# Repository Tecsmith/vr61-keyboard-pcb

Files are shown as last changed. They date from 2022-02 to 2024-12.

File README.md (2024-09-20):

# VR61 - MicroMod 60% Custom Keyboard PCB

***Featuring SparkFun's MicroMod Processor Boards***

---

> Very happy to announce that [PCBWay](https://pcbway.com) has gratefully sponsored the production of the first 5 RevA PCBs, and a partial assembly service *(all but the USB-C, Hot-Swap Sockets, JST-ph4 & SK6812's)*, for this project.
>
> Official Sponsor - PCBWay (https://pcbway.com/)
>
> Thank you [PCBWay](https://pcbway.com/)!

Please follow the updates to this production process on the [changelog](CHANGELOG.md) page.

---

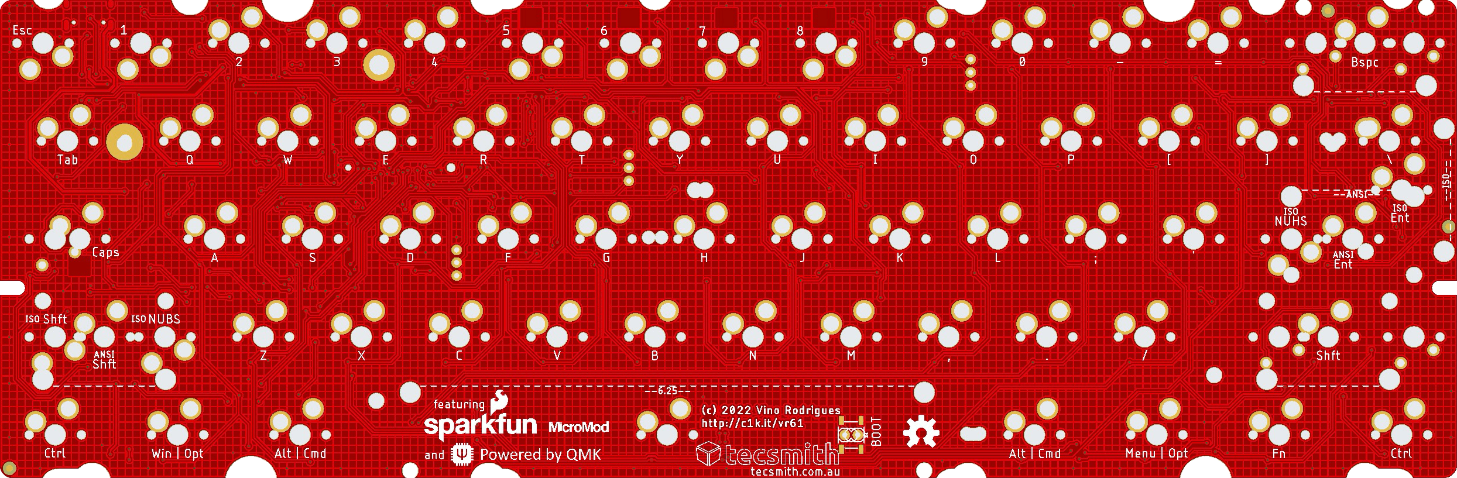
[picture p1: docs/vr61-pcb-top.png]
PCB Top View


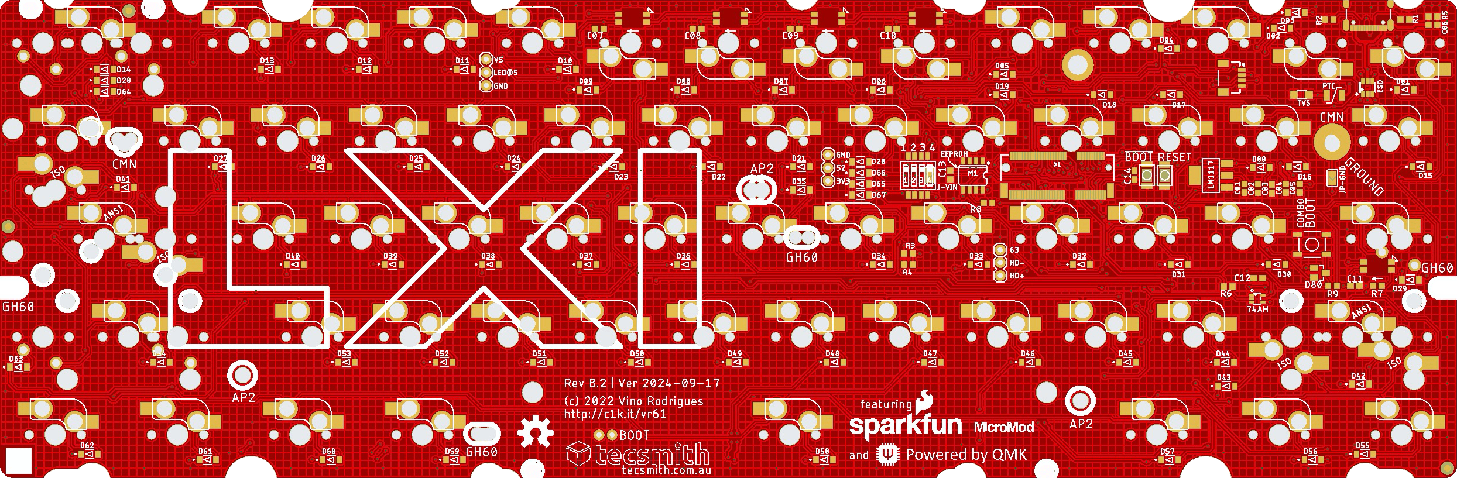
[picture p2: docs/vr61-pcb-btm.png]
PCB Bottom View


Published as Open Source, under a [ Creative Commons Share-alike 4.0 International](LICENSE.md).  

### **Rev B** &nbsp; 

> &#128077; **WORKING, OK TO BUILD**

* [PDF Schematic](docs/vr61-revB.2.pdf) <sup>1</sup>
* [EAGLE PCB](EAGLE/vr61/vr61-revB.brd)
* [EAGLE Schematic](EAGLE/vr61/vr61-revB.sch)

* Notes:
    - Keymap Working on both STM32 and PR2040
    - *(Optional EEPROM not tested yet)*

> <sup>1</sup> = *RevB.1 schematic is [here](docs/vr61-revB.pdf)*

### **Rev A** &nbsp; 

> &#9888; Do not use this revision, it has terminal flaws.

* ~~[PDF Schematic](docs/vr61-revA.pdf)~~
* ~~EAGLE PCB~~ <sup>2</sup>
* ~~EAGLE Schematic~~ <sup>2</sup>

> <sup>2</sup> = *to access these files please use the Github history*

### QMK code:

* https://github.com/Tecsmith/vr61-keyboard-qmk
* USB Identifier registered with [pid.codes](https://pid.codes/) = [`1209`/`7672`](https://pid.codes/1209/7672/)

### Layout

* [KLE link](http://www.keyboard-layout-editor.com/#/gists/c812c931186e45a5acbc3e217ef4f161)

*****

## Features

**VR61-MicroMod** - using SparkFun MicroMod STM32 or RP2040 M.2 module

### Core Design Elements

- 60% form factor
    - Design to be compatible with GH60/HK60 cases
    - Also compatible with Anne Pro 2 cases *(~~drop in~~ QMK replacement for existing AP2's or AP2 cases)* *[Removal of battery and minor case cut in the battery compartment required.]*
    - MicroMod positioned in case *"battery compartment"* space.

- QMK + VIA default f/w
    - Wired only *(no wireless)*
    - Default key-maps for Mac users

- User choice of microcontroller
    
    - [STM32 Processor](https://www.sparkfun.com/products/17713) 
        - ARM Cortex-M4, 168MHz, 1MB Flash, 192kB SRAM
        - https://github.com/Tecsmith/vr61-keyboard-qmk

    - [RP2040 Processor](https://www.sparkfun.com/products/17720) 
        - ARM Cortex-M0+, 133MHz, 128Mb Flash (16MB external), 264kB SRAM in six banks
        
- USB-C *(left side)*

    ... but also optional JST connector for [ai03 Unified C3 Daughterboard](https://github.com/ai03-2725/Unified-Daughterboard)

- ESD, Over Voltage and Over Current protection

    ... and cable shield noise filter

- Hot-swap, 5 pin switch slots

- PCB mounted stabs compatibility

- Dual ANSI / ISO layout support

- 61-Key (ANSI) / 62-Key (ISO) Layout [1.25, 1.25, 1.25, **6.25**, 1.25, 1.25, 1.25, 1.25] bottom row *(a.k.a. "Poker" / "POK3R" Layout)*

- Limited RGB LEDs *(SK6812 mini-E)*

    - RGB Caps Lock Indicator

    - North facing RGB's under the `5`, `6`, `7` & `8` keys for layer indicator

    - WS2812/SK6812 breakout for optional external LEDs

- Spare GPIO pins (`52` & `63`) breakout for expansion

   ... e.g., ~~add speaker~~

- Both `[Reset]` and `[Boot]` buttons *(as per MicroMod ref. design)*

    ... plus under space-bar Boot pins for bootload without disassembly *(press while inserting cable for bootloader function)*

---
Made with &#9829; by Vino Rodrigues

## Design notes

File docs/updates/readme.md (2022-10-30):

# Updates
All notable updates to this project will be documented in this file.

*(The format is based on [Keep a Changelog](https://keepachangelog.com/en/1.0.0/).)*

> [PCBWay](https://pcbway.com) graciously offered to sponsor the prototype build of this keyboard

<p align="center">

</p>

---

# Rev B - History

## 2022-08-30

- Placed order with PCBWay ... added Micromod and USB connector to this assembly set

## 2022-09-1

- PCBWay confirmed sourcing of all parts
- Order paid and go-ahead given

## 2022-10-17

- PCBWay order of 5 prototype bards arrived.  Some issues were encountered with the `74AHCT1G125GW` module footprint.

## 2022-10-23

- First prototype fully built
- Code implemented, but no success of getting the LED's to work

## 2022-10-27

- Finally got the LED's to work
- Issue was with the code and the PWM settings of the STM32 processor
- Cannot get the PR2040 code to work -- parking the RP2040 LED implementation, the keymap works however

## 2022-10-30

- Final code on the keymaps completed
- Minor edits to the PCB

## Pending

- PR2040 LED not working yet
- SPI EEPROM not tested *(not even attempted, yet)*

---

# Rev A - History

## 2022-06-17

- Order placed with PCBWay and confirmation received.

## 2022-06-28

### Finished goods photos sent

- Got an email will the finished build - shipping to me next.
  
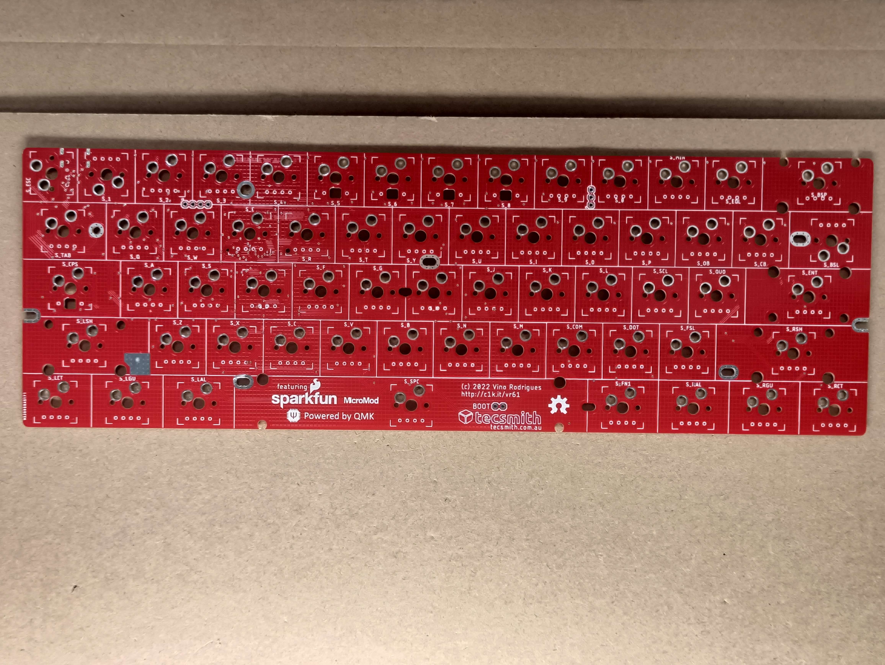
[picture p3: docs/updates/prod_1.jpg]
  
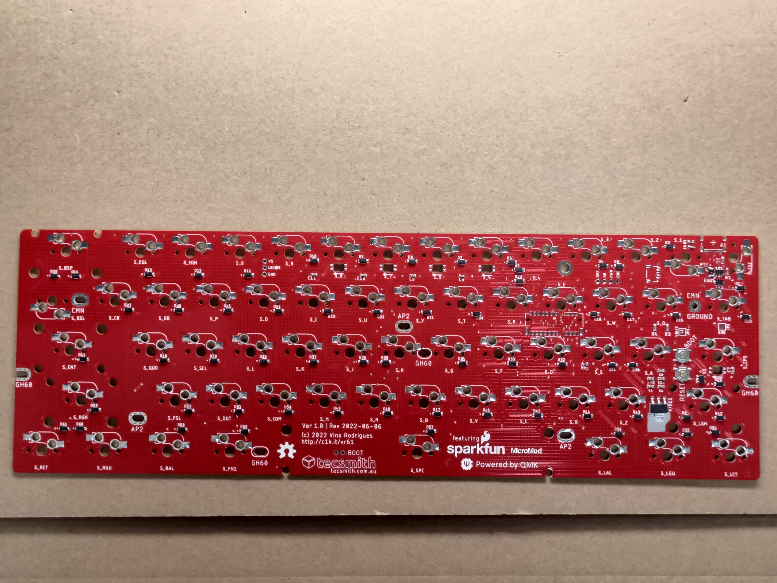
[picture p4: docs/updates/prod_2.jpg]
  
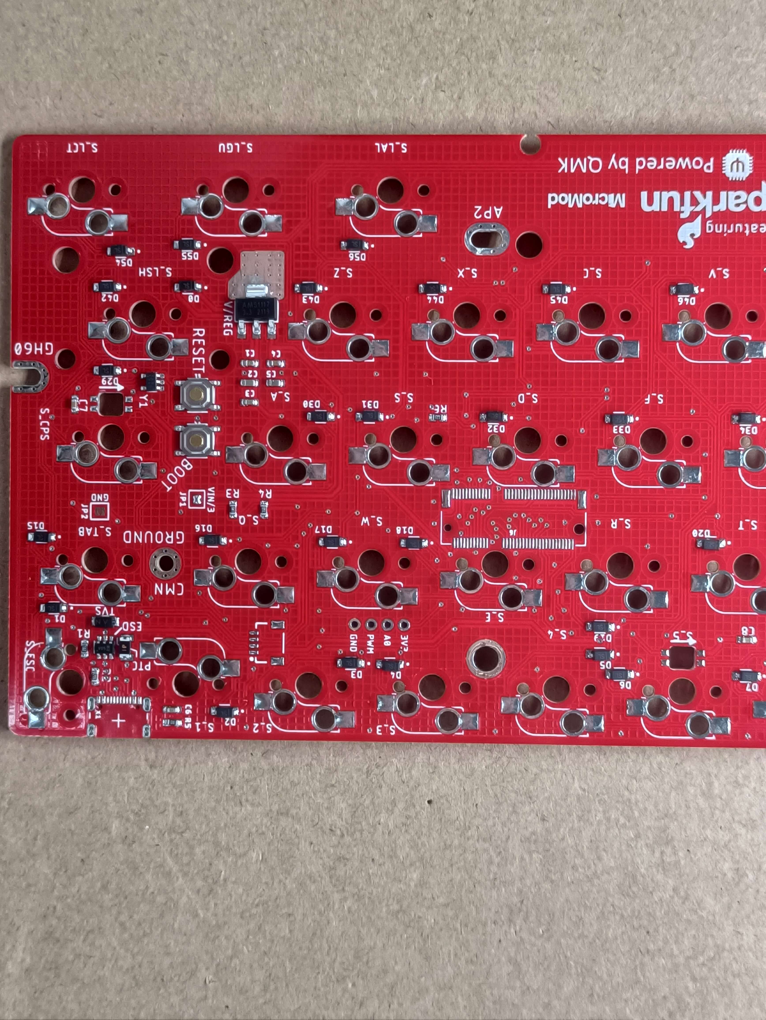
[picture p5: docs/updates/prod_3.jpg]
  
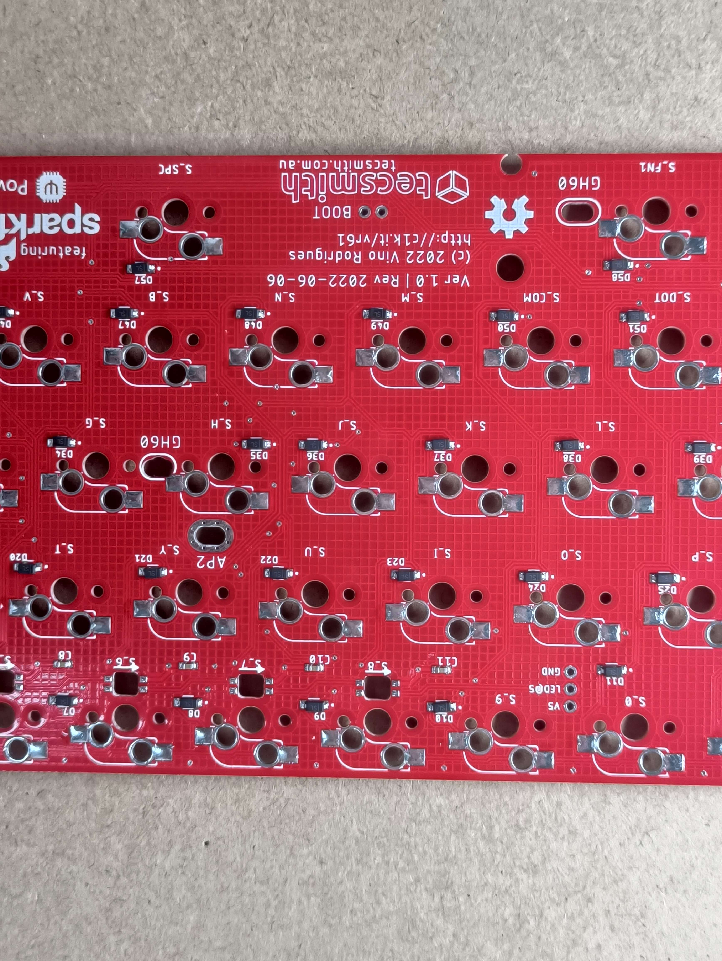
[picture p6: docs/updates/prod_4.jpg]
  
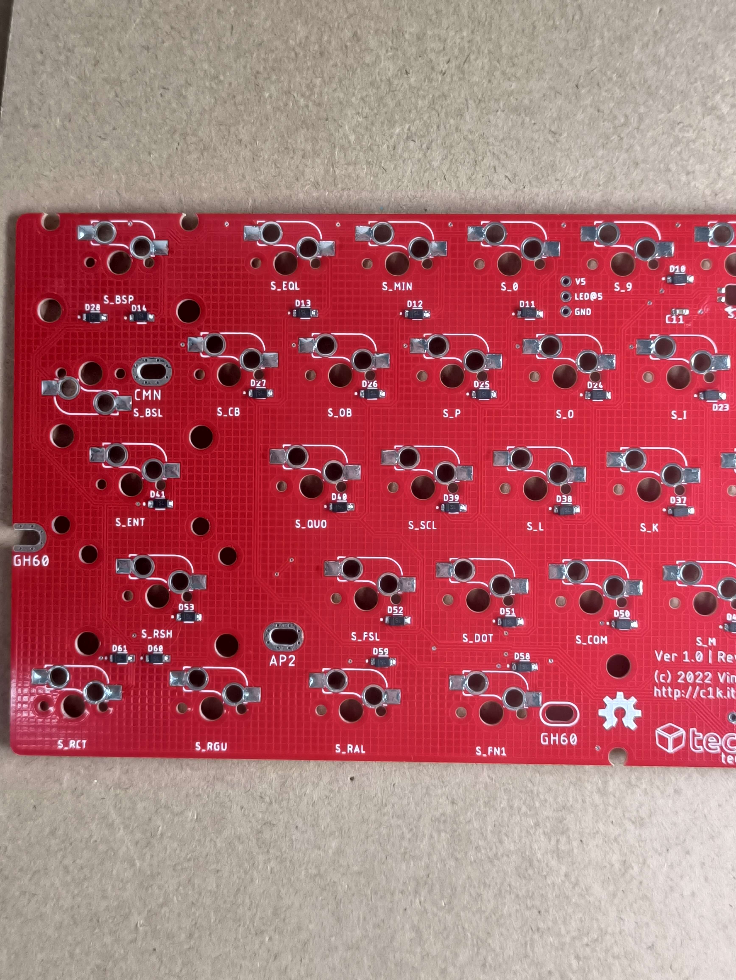
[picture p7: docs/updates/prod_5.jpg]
  

## 2022-07-15

### PCB delivered

- Arrived in Sydney via DHL.  No issues.

## 2022-07-18

### Initial testing

- Soldered on UBS connector
- Soldered on MicroMod connector
- Installed SMT32 module and Tested key matrix - ***IT WORKS!***
  - Must say I build 2 boards and both didn't work at first - fault finding lead to discovery that one of the USB data lines was grounded.  On one board I stripped out the ESD thinking that was up-side-down... it wasn't.  And then I found it.  A solder short on the MicroMod connector between pin 5 and 7... on BOTH!
  - Must also say the soldering that Micromod connector was super difficult!
  - Next time I will have all the components installed by the supplier!
- PCBWay did an amazing job on the PCB!

## 2022-07-20

### Declaring Rev A as FAILED :(

Came across some terminal issues when compiling the code and attempting to retro-fit the PCB into a AnnePro2 case.

- The `ESC` key is off to right by 1mm.  Checked the CAD `.sch` and say that somehow I'd moved it and missed that it was off by 1mm.  Must have been on the rotation and I didn't double check.
- The LED implementation does not work electronically.  Somewhere between the MCU the Level Shifter and the first LED something happens and I blow the 1st LED.  Soldered on 3 replacements, all blown. Bypass the `Caps-Lock` position and made `5` key 1st - that blew to.  Need to relook at more ref. designs for this.

#### Next

- Everything else seems to work.  Code also works...
- ... but I'd assumed the memory IC on the MicroMod was an EEPROM. **It's not** .. it's Flash! *(Rookie assumption!)*  Will implement an I²C EEPROM as the 100,000 write cycles of the W25Q32FV Flash is far, far less than the 4,000,000 of an external EEPROM like the ST M24Cx IC's.
> Wondering what I can do with the Flash tho ... seems a waste.

---

# Rev A - Issues
> as discovered ... to implement in rev. B

- [ ] ~~Position of MicroMod connector is too low, does not fit in AP2 case without minor cutting - possibly move this up as far as it can go.~~ *[Cannot move as it will interfere with key]*
- [x] Position of the BOOT pads in the space bar area should align to the AP2 slot
- [x]  Spacing of key was generated by [Kalerator](https://kalerator.clueboard.co/) ... but this generator spaces the keys at 19mm.  **However***... spacing for keyboards is **19.05mm**!

#### Post FAIL / Rev B WIP

- [x] Correct `ESC` key position
- [x] New LED / Level Shift design
- [ ] ~~Bring out I²C from Micromod~~ *[I²C not usable as pins are shared with matrix pins for PR2040 module]*
- [x] ~~Add I²C EEPROM module~~ *[Changed this to SPI]*
- [x] Move USB 0.5mm right to align to AP2 case slot. *(Uncertain this will jeopardise the GH60 cases.)*

## Maybe

- [x] Move 5678 LED's to north-facing.
- [x] Possibly incorporate a ISO layout?
- [ ] ~~Possibly incorporate a 64-key layout?~~ *[Does not fit]*

> Rev B is ready *[26 Aug 2022]*

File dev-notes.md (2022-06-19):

# Random Notes

***(Not part of the project)***

## MicroMod reference boards

- SparkFun MicroMod ATP Carrier Board - https://github.com/sparkfun/MicroMod_ATP_Carrier_Board
- SparkFun STM32 MicroMod Processor - https://github.com/sparkfun/MicroMod_STM32_Processor
- SparkFun MicroMod Processor RP2040 - https://github.com/sparkfun/MicroMod_Processor-RP2040

## Tools Used

- Layout
    - [Keyboard Layout Editor](http://www.keyboard-layout-editor.com/)
- EAGLE key position generator
    - [Kalerator](https://kalerator.clueboard.co/)
- KiCad
    - [@ai03 's PCB Designer Guide](https://wiki.ai03.com/books/pcb-design/chapter/pcb-designer-guide)
    - [@ruiqimao 's Keyboard PCB Guide](https://github.com/ruiqimao/keyboard-pcb-guide)
- Plate
    - [Swill's Plate & Case Builder](http://builder.swillkb.com/)
    - [Keyboard CAD Assistant](http://www.keyboardcad.com/)

## Possible design aids

- Closest is the BM60 Poker - but that's not open source.
- [**Acheron Project**](https://github.com/orgs/AcheronProject) - [acheronproject.com](https://acheronproject.com/)
    - [KeebsPCB](https://github.com/AcheronProject/KeebsPCB) &#x26A0;
    - [ArcticPCB](https://github.com/AcheronProject/ArcticPCB)
    - [Tsuki](https://github.com/AcheronProject/Tsuki)
    - [Doddle60](https://github.com/AcheronProject/Doddle60)
- [GH60](https://github.com/komar007/gh60), also [read this](http://blog.komar.be/gh60-evolution/)
- [Bakeneko 60](https://github.com/kkatano/bakeneko-60)
- [Voyager 60](https://github.com/ai03-2725/Voyager60)
- [Plain6-C](https://github.com/evyd13/plain60-c)
- *(a bit off the design footprint)* [Grabert KB](https://github.com/KoBussLLC/grabert-hardware)
- for M.2 example see [github.com/makerdiary/python-keyboard](https://github.com/makerdiary/python-keyboard) & [makerdiary.com/m60](https://makerdiary.com/pages/m60-mechanical-keyboard)

## @tzarc Notes

Explicitly listed below, pins are available on all of:
> STM32, SAMD51, Teensy, RP2040, nRF52

- A0/A1 available
- PWM0/PWM1 available
- D0/D1 available
- G0-G3 available
- AUD LRCLK/BCLK available
- I2C SCL/SDA/INT available
- SPI SCK/SDO/SDI/CS available

further:

- G4-G7 are unusable on RP2040 (collides with SPI)
- CAN only available on STM32, SAMD51, Teensy
- G11/SWO only available on STM32, SAMD51, Teensy

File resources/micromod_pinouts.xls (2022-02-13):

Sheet: Sheet1
 | STM32 PROCESSOR PINOUT |  |  |  |  |  |  |  | MICROMOD GENERAL PINOUT TABLE
 | STM32 Pin | Primary Function | Bottom | Top | Primary Function | STM32 Pin |  |  | Function |  |  |  | Bottom | Top | Function
 |  |  | Pin | Pin |  |  |  |  |  |  |  |  | Pin | Pin
 | - | (Not Connected) |  | 75 | GND | - |  |  |  |  |  | (Not Connected) |  | 75 | GND
 | - | 3.3V | 74 | 73 | G5 / BUS5 | PC13 | C13 |  |  |  |  | 3.3V | 74 | 73 | G5 / BUS5 |  |  | ?
 | - | - | 72 | 71 | G6 / BUS6 | PC2 | C2 |  |  |  |  | RTC_3V_BATT | 72 | 71 | G6 / BUS6 |  |  | ?
 | - | - | 70 | 69 | - | - |  |  |  |  | SPI_CS1# | SDIO_DATA3 (I/O) | 70 | 69 | G7 / BUS7
 | - | - | 68 | 67 | - | - |  |  |  |  |  | SDIO_DATA2 (I/O) | 68 | 67 | G8
 | - | - | 66 | 65 | - | - |  |  |  |  |  | SDIO_DATA1 (I/O) | 66 | 65 | G9 | ADC_D- | CAM_HSYNC
 | - | - | 64 | 63 | G10/HOST_VBUS | PB13 | ⚠ |  |  |  | SPI_CIPO1 | SDIO_DATA0 (I/O) | 64 | 63 | G10 | ADC_D+ | CAM_VSYNC
 | - | - | 62 | 61 | SPI_CIPO (I) | PA6 | A6 |  |  |  | SPI COPI1 | SDIO_CMD (I/O) | 62 | 61 | SPI_CIPO (I) |  |  | ROW0
 | - | - | 60 | 59 | SPI_COPI (O) | PA7 | A7 |  |  |  | SPI SCK1 | SDIO_SCK (O) | 60 | 59 | SPI_COPI (O) | LED_DAT
 | - | - | 58 | 57 | SPI_SCK (O) | PA5 | A5 |  |  |  |  | AUD_MCLK (O) | 58 | 57 | SPI_SCK (O) | LED_CLK
B4 | PB4 | AUD_OUT | 56 | 55 | SPI_CS# | PC4 | C4 | COL0 | CAM_MCLK | PCM_OUT | I2S_OUT | AUD_OUT | 56 | 55 | SPI_CS# |  |  | ROW1
B5 | PB5 | AUD_IN | 54 | 53 | I2C_SCL1 (I/O) | PB6 | B6 | COL1 | CAM_PCLK | PCM_IN | I2S_IN | AUD_IN | 54 | 53 | I2C_SCL1 (I/O) |  |  | ROW2
A4 | PA4 | AUD_LRCLK | 52 | 51 | I2C_SDA1 (I/O) | PB7 | B7 | COL2 | PDM_DATA | PCM_SYNC | I2S_WS | AUD_LRCLK | 52 | 51 | I2C_SDA1 (I/O) |  |  | ROW3
B3 | PB3 | AUD_BCLK | 50 | 49 | BATT_VIN / 3 (I - ADC) (0 to 3.3V) | - |  | COL3 | PDM_CLK | PCM_CLK | I2S_SCK | AUD_BCLK | 50 | 49 | BATT_VIN / 3 (I - ADC) (0 to 3.3V)
C9 | PC9 | G4 / BUS4 | 48 | 47 | PWM1 | PC7 | C7 | COL4 |  |  |  | G4 / BUS4 | 48 | 47 | PWM1 |  |  | ROW4
C8 | PC8 | G3 / BUS3 | 46 | 45 | GND | - |  | COL5 |  |  |  | G3 / BUS3 | 46 | 45 | GND
A0 | PA0 | G2 / BUS2 | 44 | 43 | CAN_TX | PB9 | B9 | COL6 |  |  |  | G2 / BUS2 | 44 | 43 | CAN_TX |  |  | ?
A8 | PA8 | G1 / BUS1 | 42 | 41 | CAN_RX | PB8 | B8 | COL7 |  |  |  | G1 / BUS1 | 42 | 41 | CAN_RX |  |  | ?
D2 | PD2 | G0 / BUS0 | 40 | 39 | GND | - |  | COL8 |  |  |  | G0 / BUS0 | 40 | 39 | GND
B0 | PB0 | A1 | 38 | 37 | USBHOST_D- | PB14 | B14 | COL9 |  |  |  | A1 | 38 | 37 | USBHOST_D-
 | - | GND | 36 | 35 | USBHOST_D+ | PB15 | B15 | COL10 |  |  |  | GND | 36 | 35 | USBHOST_D+
C5 | PC5 | A0 | 34 | 33 | GND | - |  |  |  |  |  | A0 | 34 | 33 | GND
C6 | PC6 | PWM0 | 32 | 31 | Module Key | - |  | CAPS-LED |  |  |  | PWM0 | 32 | 31 | Module Key
 | - | Module Key | 30 | 29 | Module Key | - |  |  |  |  |  | Module Key | 30 | 29 | Module Key
 | - | Module Key | 28 | 27 | Module Key | - |  |  |  |  |  | Module Key | 28 | 27 | Module Key
 | - | Module Key | 26 | 25 | Module Key | - |  |  |  |  |  | Module Key | 26 | 25 | Module Key
 | - | Module Key | 24 | 23 | SWDIO | PA13 | A14 |  |  |  |  | Module Key | 24 | 23 | SWDIO |  |  | ?
 | - | - | 22 | 21 | SWCLK | PA14 | A13 |  |  |  |  | UART_TX2 (O) | 22 | 21 | SWDCK |  |  | ?
 | - | - | 20 | 19 | UART_RX1 (I) | PA3 | A3 |  |  |  |  | UART_RX2 (I) | 20 | 19 | UART_RX1 (I) |  |  | ?
C1 | PC1 | D1 | 18 | 17 | UART_TX1 (0) | PA2 | A2 | COL11 |  |  | CAM_TRIG | D1 | 18 | 17 | UART_TX1 (0) |  |  | ?
B1 | PB1 | I2C_INT# | 16 | 15 | - | - |  |  |  |  |  | I2C_INT# | 16 | 15 | UART_CTS1 (I)
B10 | PB10 | I2C_SCL (I/0) | 14 | 13 | - | - |  |  |  |  |  | I2C_SCL (I/0) | 14 | 13 | UART_RTS1 (O)
B11 | PB11 | I2C_SDA (I/0) | 12 | 11 | BOOT# (I - Open Drain) | BOOT0 | BOOT ⚠ |  |  |  |  | I2C_SDA (I/0) | 12 | 11 | BOOT (I - Open Drain) |  |  | BOOT ⚠
C0 | PC0 | D0 | 10 | 9 | - | - |  | COL12 |  |  |  | D0 | 10 | 9 | USB_VIN
B12 | PB12 | G11/HOST_ID | 8 | 7 | GND | - |  | COL13 |  |  | SWO | G11 | 8 | 7 | GND
⚠ RESET | - | RESET# (I - Open Drain) | 6 | 5 | USB_D- | PA11 | ⚠ | ⚠ RESET |  |  |  | RESET# (I - Open Drain) | 6 | 5 | USB_D- |  |  | USB D-
 | - | - | 4 | 3 | USB_D+ | PA12 | ⚠ |  |  |  |  | 3.3V_EN | 4 | 3 | USB_D+ |  |  | USB D+
 | - | 3.3V | 2 | 1 | GND | - |  |  |  |  |  | 3.3V | 2 | 1 | GND
 | AUDIO
 | UART
 | GPIO/BUS
 | I2C
 | SDIO
 | SPI
 | Dedicated

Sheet: Sheet2
MICROMOD GENERAL PIN DESCRIPTIONS
Signal Group | Signal | I/O | Description | Voltage
Power | 3.3V | I | 3.3V Source | 3.3V
 | GND |  | Return current path | 0V
 | USB_VIN | I | USB VIN compliant to USB 2.0 specification. Connect to pins on processor board that require 5V for USB functionality | 4.8-5.2V
 | RTC_3V_BATT | I | 3V provided by external coin cell or mini battery. Max draw=100μA. Connect to pins maintaining an RTC during power loss. Can be left NC. | 3V
 | 3.3V_EN | O | Controls the carrier board's main voltage regulator. Voltage above 1V will enable 3.3V power path. | 3.3V
 | BATT_VIN/3 | I | Carrier board raw voltage over 3. 1/3 resistor divider is implemented on carrier board. Amplify the analog signal as needed for full 0-3.3V range | 3.3V
Reset | Reset | I | Input to processor. Open drain with pullup on processor board. Pulling low resets processor. | 3.3V
 | Boot | I | Input to processor. Open drain with pullup on processor board. Pulling low puts processor into special boot mode. Can be left NC. | 3.3V
USB | USB_D± | I/O | USB Data ±. Differential serial data interface compliant to USB 2.0 specification. If UART is required for programming, USB± must be routed to a USB-to-serial conversion IC on the processor board.
USB Host | USBHOST_D± | I/O | For processors that support USB Host Mode. USB Data±. Differential serial data interface compliant to USB 2.0 specification. Can be left NC.
CAN | CAN_RX | I | CAN Bus receive data. | 3.3V
 | CAN_TX | O | CAN Bus transmit data. | 3.3V
UART | UART_RX1 | I | UART receive data. | 3.3V
 | UART_TX1 | O | UART transmit data. | 3.3V
 | UART_RTS1 | O | UART ready to send. | 3.3V
 | UART_CTS1 | I | UART clear to send. | 3.3V
 | UART_RX2 | I | 2nd UART receive data. | 3.3V
 | UART_TX2 | O | 2nd UART transmit data. | 3.3V
I2C | I2C_SCL | I/O | I2C clock. Open drain with pullup on carrier board. | 3.3V
 | I2C_SDA | I/O | I2C data. Open drain with pullup on carrier board | 3.3V
 | I2C_INT# | I | Interrupt notification from carrier board to processor. Open drain with pullup on carrier board. Active LOW | 3.3V
 | I2C_SCL1 | I/O | 2nd I2C clock. Open drain with pullup on carrier board. | 3.3V
 | I2C_SDA1 | I/O | 2nd I2C data. Open drain with pullup on carrier board. | 3.3V
SPI | SPI_COPI | O | SPI Controller Output/Peripheral Input. | 3.3V
 | SPI_CIPO | I | SPI Controller Input/Peripheral Output. | 3.3V
 | SPI_SCK | O | SPI Clock. | 3.3V
 | SPI_CS# | O | SPI Chip Select. Active LOW. Can be routed to GPIO if hardware CS is unused. | 3.3V
SPI/SDIO | SPI_SCK1/SDIO_CLK | O | 2nd SPI Clock. Secondary use is SDIO Clock. | 3.3V
 | SPI_COPI1/SDIO_CMD | I/O | 2nd SPI Controller Output/Peripheral Input. Secondary use is SDIO command interface. | 3.3V
 | SPI_CIPO1/SDIO_DATA0 | I/O | 2nd SPI Peripheral Input/Controller Output. Secondary use is SDIO data exchange bit 0. | 3.3V
 | SDIO_DATA1 | I/O | SDIO data exchange bit 1. | 3.3V
 | SDIO_DATA2 | I/O | SDIO data exchange bit 2. | 3.3V
 | SPI_CS1/SDIO_DATA3 | I/O | 2nd SPI Chip Select. Secondary use is SDIO data exchange bit 3. | 3.3V
Audio | AUD_MCLK | O | Audio master clock. | 3.3V
 | AUD_OUT/PCM_OUT/I2S_OUT/CAM_MCLK | O | Audio data output. PCM synchronous data output. I2S serial data out. Camera master clock. | 3.3V
 | AUD_IN/PCM_IN/I2S_IN/CAM_PCLK | I | Audio data input. PCM syncrhonous data input. I2S serial data in. Camera periphperal clock. | 3.3V
 | AUD_LRCLK/PCM_SYNC/I2S_WS/PDM_DATA | I/O | Audio left/right clock. PCM syncrhonous data SYNC. I2S word select. PDM data. | 3.3V
 | AUD_BCLK/PCM_CLK/I2S_CLK/PDM_CLK | O | Audio bit clock. PCM clock. I2S continuous serial clock. PDM clock. | 3.3V
SWD | SWDIO | I/O | Serial Wire Debug I/O. Connect if processor board supports SWD. Can be left NC. | 3.3V
 | SWDCK | I | Serial Wire Debug clock. Connect if processor board supports SWD. Can be left NC. | 3.3V
ADC | A0 | I | Analog to digital converter 0. Amplify the analog signal as needed to enable full 0-3.3V range. | 3.3V
 | A1 | I | Analog to digital converter 1. Amplify the analog signal as needed to enable full 0-3.3V range. | 3.3V
PWM | PWM0 | O | Pulse width modulated output 0. | 3.3V
 | PWM1 | O | Pulse width modulated output 1. | 3.3V
Digital | D0 | I/O | General digital input/output pin. | 3.3V
 | D1/CAM_TRIG | I/O | General digital input/output pin. Camera trigger. | 3.3V
General/Bus | G0/BUS0 | I/O | General purpose pins. Any unused processor pins should be assigned to Gx with ADC + PWM capable pins given priority (0, 1, 2, etc.) positions. The intent is to guarantee PWM, ADC and Digital Pin functionality on respective ADC/PWM/Digital pins. Gx pins do not guarantee ADC/PWM function. Alternative use is pins can support a fast read/write 8-bit or 4-bit wide bus. | 3.3V
 | G1/BUS1 | I/O |  | 3.3V
 | G2/BUS2 | I/O |  | 3.3V
 | G3/BUS3 | I/O |  | 3.3V
 | G4/BUS4 | I/O |  | 3.3V
 | G5/BUS5 | I/O |  | 3.3V
 | G6/BUS6 | I/O |  | 3.3V
 | G7/BUS7 | I/O |  | 3.3V
 | G8 | I/O | General purpose pin | 3.3V
 | G9/ADC_D-/CAM_HSYNC | I/O | Differential ADC input if available. Camera horizontal sync. | 3.3V
 | G10/ADC_D+/CAM_VSYNC | I/O | Differential ADC input if available. Camera vertical sync. | 3.3V
 | G11/SWO | I/O | General purpose pin. Serial Wire Output | 3.3V

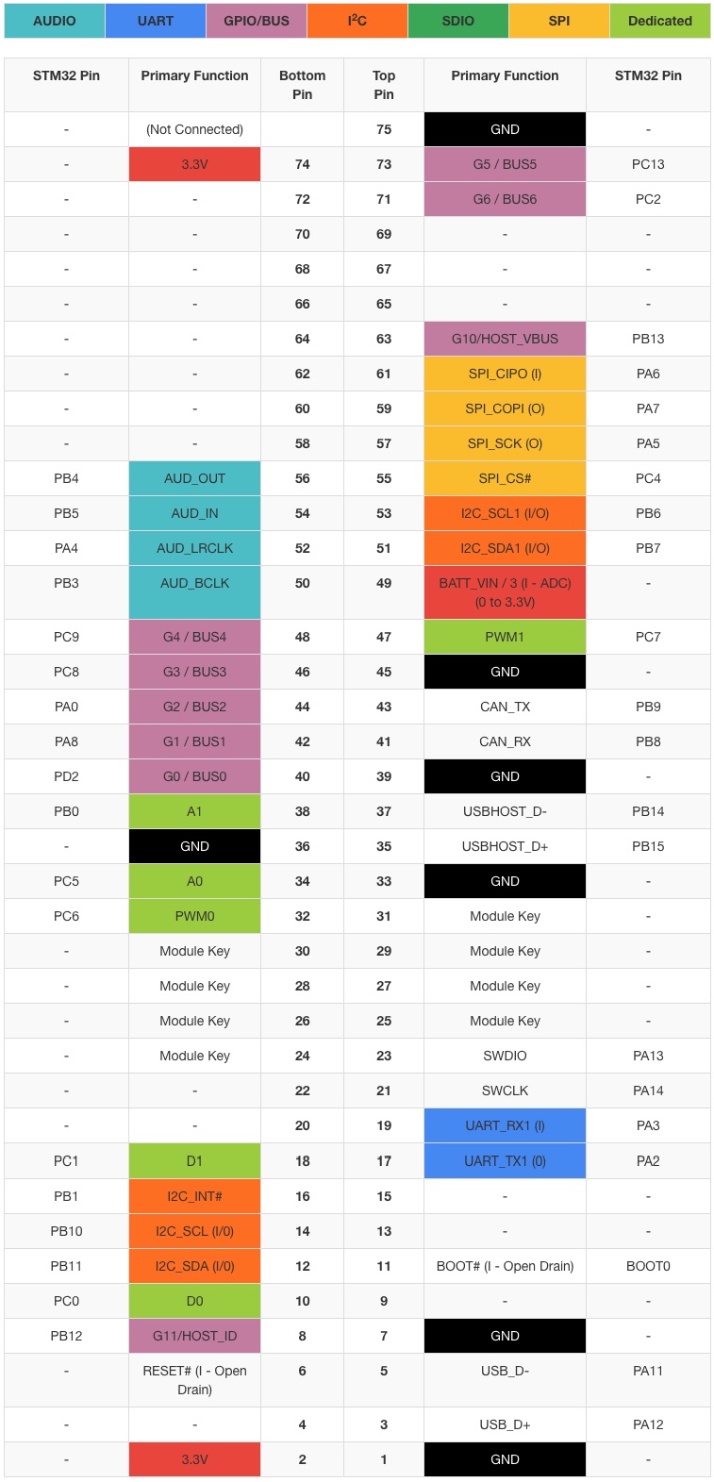
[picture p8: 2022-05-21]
docs/sparkfun_stm32/stm32-pinout.jpg

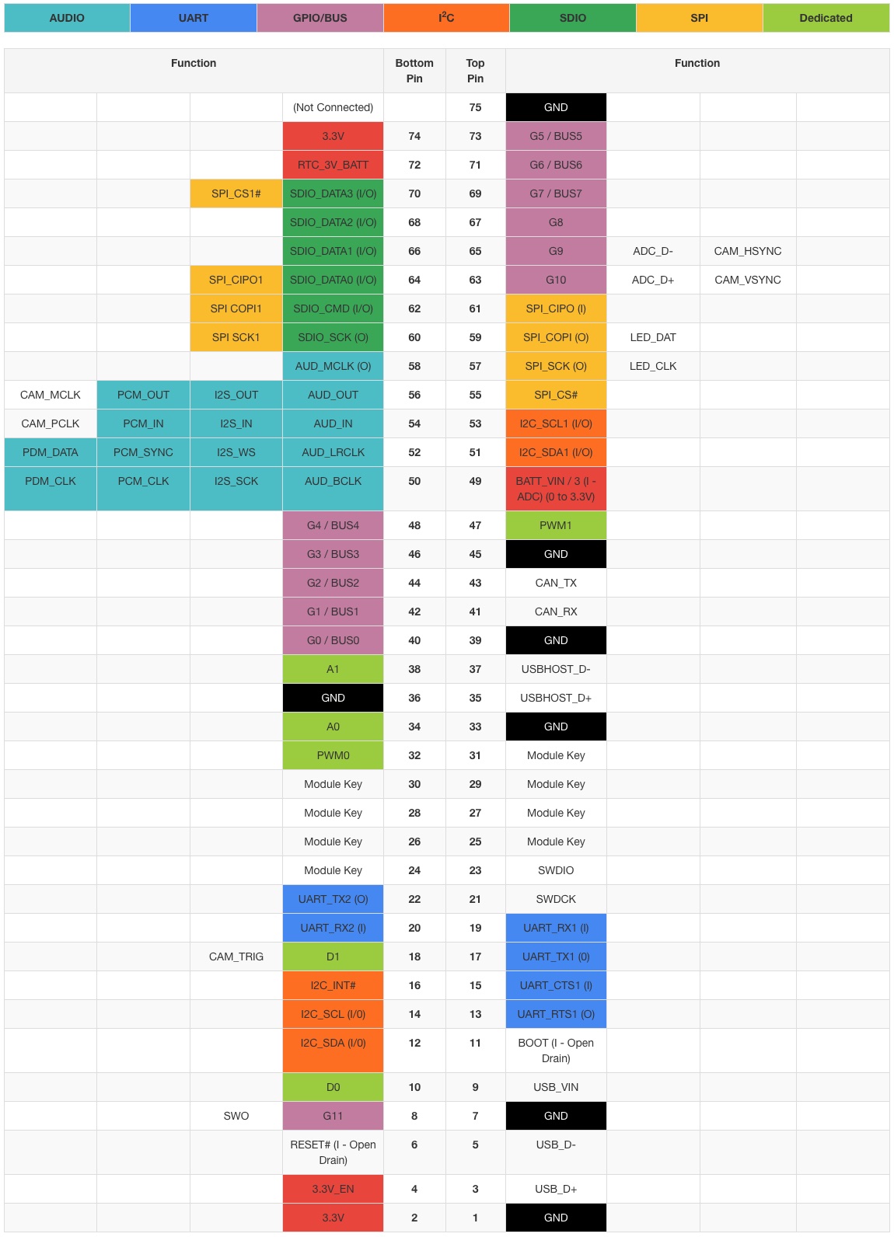
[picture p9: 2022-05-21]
docs/sparkfun_atp/micromod-pinout.jpg

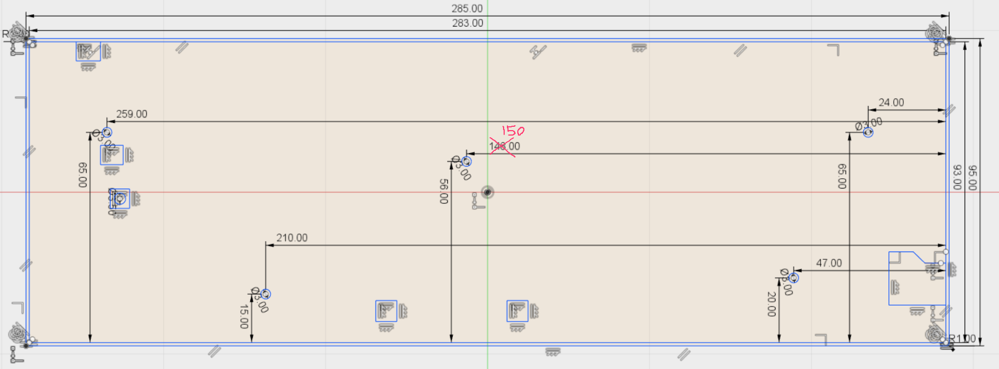
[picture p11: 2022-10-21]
docs/ref_pcb_dims/AP2_dims.png

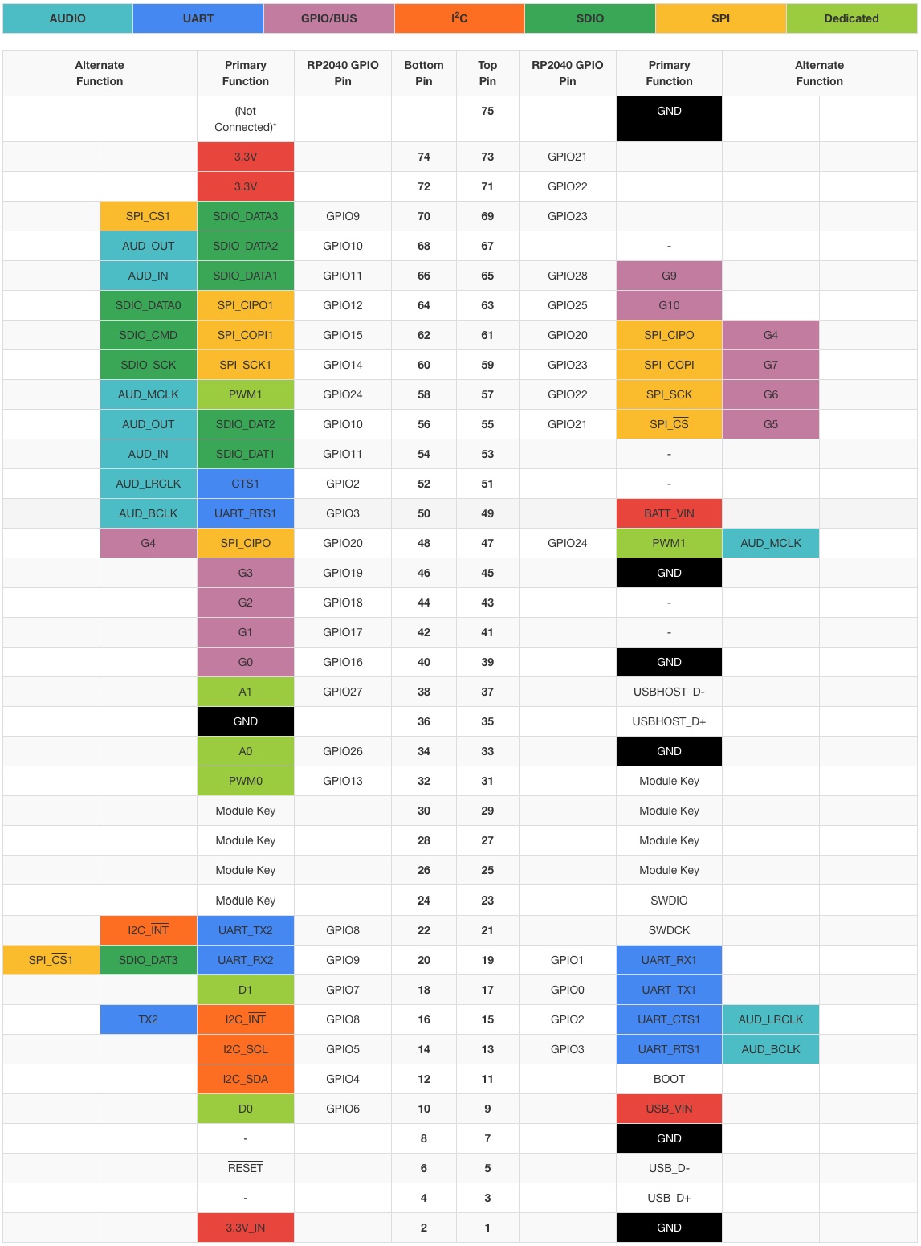
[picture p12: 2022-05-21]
docs/sparkfun_rp2040/sparkfun-rp2040.jpg

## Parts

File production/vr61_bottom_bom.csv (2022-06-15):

Comment | Designator | Footprint | LCSC Part # | Mnf Part #
100nF | C1 C4 C7 C8 C9 C10 C11 | C0603 | C14663 | CC0603KRX7R9BB104
22uF | C2 C5 | C0603 | C59461 | CL10A226MQ8NRNC
4.7nF | C3 C6 | C0603 | C53987 | 0603B472K500NT
Schottky | D0 D1 D2 D3 D4 D5 D6 D7 D8 D9 D10 D11 D12 D13 D14 D15 D16 D17 D18 D19 D20 D21 D22 D23 D24 D25 D26 D27 D28 D29 D30 D31 D32 D33 D34 D35 D36 D37 D38 D39 D40 D41 D42 D43 D44 D45 D46 D47 D48 D49 D50 D51 D52 D53 D54 D55 D56 D57 D58 D59 D60 D61 | SOD-123 | C8598 | B5819W SL
ESD_SRV05-4 | ESD | SOT-23-6L | C371093
SM04B-SRSS-TB(LF)(SN) | J2 | 1X04_1MM_RA | C160404
AMS1117-3.3 | LM1117 | SOT223 | C6186
PTC_ASMD1206 | PTC | SMD_PTC | C135341
5.1Kohm | R1 R2 | R0603 | C23186 | 0603WAF5101T5E
150Kohm | R3 | R0603 | C22807 | 0603WAF1503T5E
75Kohm | R4 | R0603 | C23242 | 0603WAF7502T5E
1Mohm | R5 | R0603 | C22935 | 0603WAF1004T5E
220ohm | R6 | R0603 | C22962 | 0603WAF2200T5E
Tactile SW | S1 S2 | TACTILE_SWITCH_SMD_5.2MM | C92584 | K2-1187SQ-A4SW-06
TVS_SMF9.0CA | TVS | SOD123FL-BI | C123799
74AHCT1G125 | Y1 | SOT-23-5 | C7484 | SN74AHCT1G125DBVR

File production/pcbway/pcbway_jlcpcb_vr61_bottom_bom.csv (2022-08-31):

Item # | Designator | Qty | Manufacturer | Mfg Part # | Description / Value | Package/Footprint | Type | Your Instructions / Notes | LCSC Part #
1 | D00,D01,D02,D03,D04,D05,D06,D07,D08,D09,D10,D11,D12,D13,D14,D15,D16,D17,D18,D19,D20,D21,D22,D23,D24,D25,D26,D27,D28,D29,D30,D31,D32,D33,D34,D35,D36,D37,D38,D39,D40,D41,D42,D43,D44,D45,D46,D47,D48,D49,D50,D51,D52,D53,D54,D55,D56,D57,D58,D59,D60,D61,D62 | 63 |  | B5819W SL | Schottky | SOD-123 | smd | Diode | C8598
2 | C12 | 1 |  | CC0603KRX7R9BB104 | 0.1uF | C0603 | smd | Capacitor | C14663
3 | C06 | 1 |  | 0603B472K500NT | 4.7nF | C0603 | smd | Capacitor | C53987
4 | C03 | 1 |  | 0603X475K100NT | 4.7uF | C0603 | smd | Capacitor | C69182
5 | C02,C05 | 2 |  | CL10A226MQ8NRNC | 22uF | C0603 | smd | Capacitor | C59461
6 | C01,C04,C07,C08,C09,C10,C11,C13 | 8 |  | CC0603KRX7R9BB104 | 100nF | C0603 | smd | Capacitor | C14663
7 | R1,R2,R8 | 3 |  | 0603WAF5101T5E | 5.1K | R0603 | smd | Resistor | C23186
8 | R4 | 1 |  | 0603WAF7502T5E | 75K | R0603 | smd | Resistor | C23242
9 | R3 | 1 |  | 0603WAF1503T5E | 150K | R0603 | smd | Resistor | C22807
10 | R6 | 1 |  | 0603WAF2200T5E | 220ohm | R0603 | smd | Resistor | C22962
11 | R7 | 1 |  | 0603WAF4700T5E | 470ohm | R0603 | smd | Resistor | C23179
12 | R5 | 1 |  | 0603WAF1004T5E | 1000K | R0603 | smd | Resistor | C22935
13 | S1,S2 | 2 |  | K2-1187SQ-A4SW-06 | Button | TACTILE_SWITCH_SMD_5.2MM | smd | K2-1187SQ-A4SW-06 | C92584
14 | LM1117 | 1 |  | AMS1117-3.3 | AMS1117-3.3 | SOT223 | smd | AMS1117-3.3 | C6186
15 | U$14 | 1 |  | 74AHCT1G125GV,125 | 74AHCT1G125GV | SC-74A | smd | 74AHCT1G125GV (Level Shifter) | C12494
16 | ESD | 1 |  | SRV05-4ATCT | ESD_SRV05-4 | SOT-23-6L | smd | ESD_SRV05-4 | C371093
17 | PTC | 1 |  | ASMD1206-150 | PTC_ASMD1206-150 | SMD_PTC | smd | PTC_ASMD1206 | C135341
18 | TVS | 1 |  | SMF9.0CA | TVS_SMF9.0CA | SOD123FL-BI | smd | SMF9.0CA | C123799
19 | J-UBS | 1 |  | KH-TYPE-C-16P | USB-C-16P | USB-C-16P | smd & thd | USB-C-16P (USB C Connector) | C709357
20 | J-UDB | 1 |  | SM04B-SRSS-TB(LF)(SN) | JST4 connector | JST 1x4P | smd | SM04B-SRSS-TB | C160404
21 | X1 | 1 |  | 2199230-4 | MICROMOD-2222-C | M.2-CONNECTOR-E | smd | https://www.te.com/usa-en/product-2199230-4.html | C2977809

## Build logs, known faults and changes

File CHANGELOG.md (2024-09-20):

# Updates
All notable updates to this project will be documented in this file.

*(The format is based on [Keep a Changelog](https://keepachangelog.com/en/1.0.0/).)*

> [PCBWay](https://pcbway.com) graciously offered to sponsor the prototype build of this keyboard

<p align="center">

</p>

---

# Rev B - History

## 2024-09-17

> *a.k.a.* **Rev B.2**

### Added

- 4-pin DIP switch
  - 1..3 consume empty switch slots.
  - 4 is the VIN sensor switch for the MicroMod
- 3x Manufacturing fiduciary marks
- Expanded options for solder-on, or Mill-Max socket switches *(does not use hot-swap sockets)*
  - Split Right Shift
  - Split Backspace
  - Stepped Caps-Lock
- Added PCB edge slots to support Bakeneko type cases

### Changed

- Licence changed from MIT to [CC BY-SA 4.0](LICENCE.md) in compliance with the SparkFun MicroMod Licence.
- Maved to latest footprints of the Tecsmith [`ts-eagle-lib`](https://github.com/Tecsmith/ts-eagle-lib) keyboard library
  - MX key
  - MX Stabs
  - SK6821 LED
- Taces now route to socket via pads, not SMD hotswap pads as these may tear off in a desoldering scenario.
- Ajusted Ground Plane mesh/hash as former model had differeing setting for top and bottom
- Revised Boot button.  *(MicroMod provides 2 button reset/boot but both are ground based, so can be consolodated into one.)*

## 2022-08-30

- Placed order with PCBWay ... added Micromod and USB connector to this assembly set

## 2022-09-1

- PCBWay confirmed sourcing of all parts
- Order paid and go-ahead given

## 2022-10-17

- PCBWay order of 5 prototype bards arrived.  Some issues were encountered with the `74AHCT1G125GW` module footprint.

## 2022-10-23

- First prototype fully built
- Code implemented, but no success of getting the LED's to work

## 2022-10-27

- Finally got the LED's to work
- Issue was with the code and the PWM settings of the STM32 processor
- Cannot get the PR2040 code to work -- parking the RP2040 LED implementation, the keymap works however

## 2022-10-30

- Final code on the keymaps completed
- Minor edits to the PCB

## Pending

- PR2040 LED not working yet
- SPI EEPROM not tested *(not even attempted, yet)*

---

# Rev A - History

## 2022-06-17

- Order placed with PCBWay and confirmation received.

## 2022-06-28

### Finished goods photos sent

- Got an email will the finished build - shipping to me next.
  
  
  
  
  
  

## 2022-07-15

### PCB delivered

- Arrived in Sydney via DHL.  No issues.

## 2022-07-18

### Initial testing

- Soldered on UBS connector
- Soldered on MicroMod connector
- Installed SMT32 module and Tested key matrix - ***IT WORKS!***
  - Must say I build 2 boards and both didn't work at first - fault finding lead to discovery that one of the USB data lines was grounded.  On one board I stripped out the ESD thinking that was up-side-down... it wasn't.  And then I found it.  A solder short on the MicroMod connector between pin 5 and 7... on BOTH!
  - Must also say the soldering that Micromod connector was super difficult!
  - Next time I will have all the components installed by the supplier!
- PCBWay did an amazing job on the PCB!

## 2022-07-20

### Declaring Rev A as FAILED :(

Came across some terminal issues when compiling the code and attempting to retro-fit the PCB into a AnnePro2 case.

- The `ESC` key is off to right by 1mm.  Checked the CAD `.sch` and say that somehow I'd moved it and missed that it was off by 1mm.  Must have been on the rotation and I didn't double check.
- The LED implementation does not work electronically.  Somewhere between the MCU the Level Shifter and the first LED something happens and I blow the 1st LED.  Soldered on 3 replacements, all blown. Bypass the `Caps-Lock` position and made `5` key 1st - that blew to.  Need to relook at more ref. designs for this.

#### Next

- Everything else seems to work.  Code also works...
- ... but I'd assumed the memory IC on the MicroMod was an EEPROM. **It's not** .. it's Flash! *(Rookie assumption!)*  Will implement an I²C EEPROM as the 100,000 write cycles of the W25Q32FV Flash is far, far less than the 4,000,000 of an external EEPROM like the ST M24Cx IC's.
> Wondering what I can do with the Flash tho ... seems a waste.

---

# Rev A - Issues
> as discovered ... to implement in rev. B

- [ ] ~~Position of MicroMod connector is too low, does not fit in AP2 case without minor cutting - possibly move this up as far as it can go.~~ *[Cannot move as it will interfere with key]*
- [x] Position of the BOOT pads in the space bar area should align to the AP2 slot
- [x]  Spacing of key was generated by [Kalerator](https://kalerator.clueboard.co/) ... but this generator spaces the keys at 19mm.  **However***... spacing for keyboards is **19.05mm**!

#### Post FAIL / Rev B WIP

- [x] Correct `ESC` key position
- [x] New LED / Level Shift design
- [ ] ~~Bring out I²C from Micromod~~ *[I²C not usable as pins are shared with matrix pins for PR2040 module]*
- [x] ~~Add I²C EEPROM module~~ *[Changed this to SPI]*
- [x] Move USB 0.5mm right to align to AP2 case slot. *(Uncertain this will jeopardise the GH60 cases.)*

## Maybe

- [x] Move 5678 LED's to north-facing.
- [x] Possibly incorporate a ISO layout?
- [ ] ~~Possibly incorporate a 64-key layout?~~ *[Does not fit]*

> Rev B is ready *[26 Aug 2022]*

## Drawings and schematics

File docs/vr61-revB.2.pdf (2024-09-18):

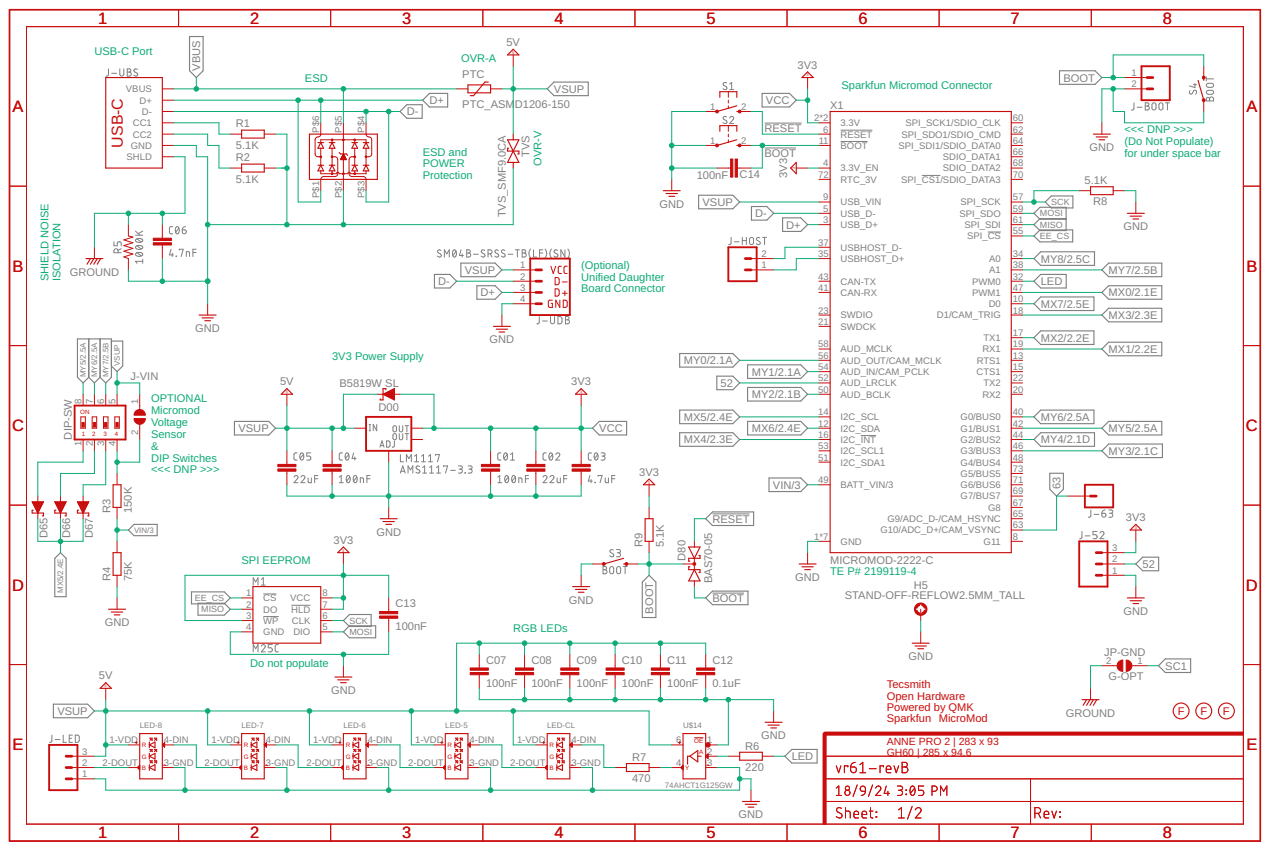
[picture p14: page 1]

<<< DNP >>>
(Do Not Populate)
GND
for under space bar

(Optional)
Unified Daughter Board Connector

Tecsmith
Open Hardware Sparkfun Powered by QMK

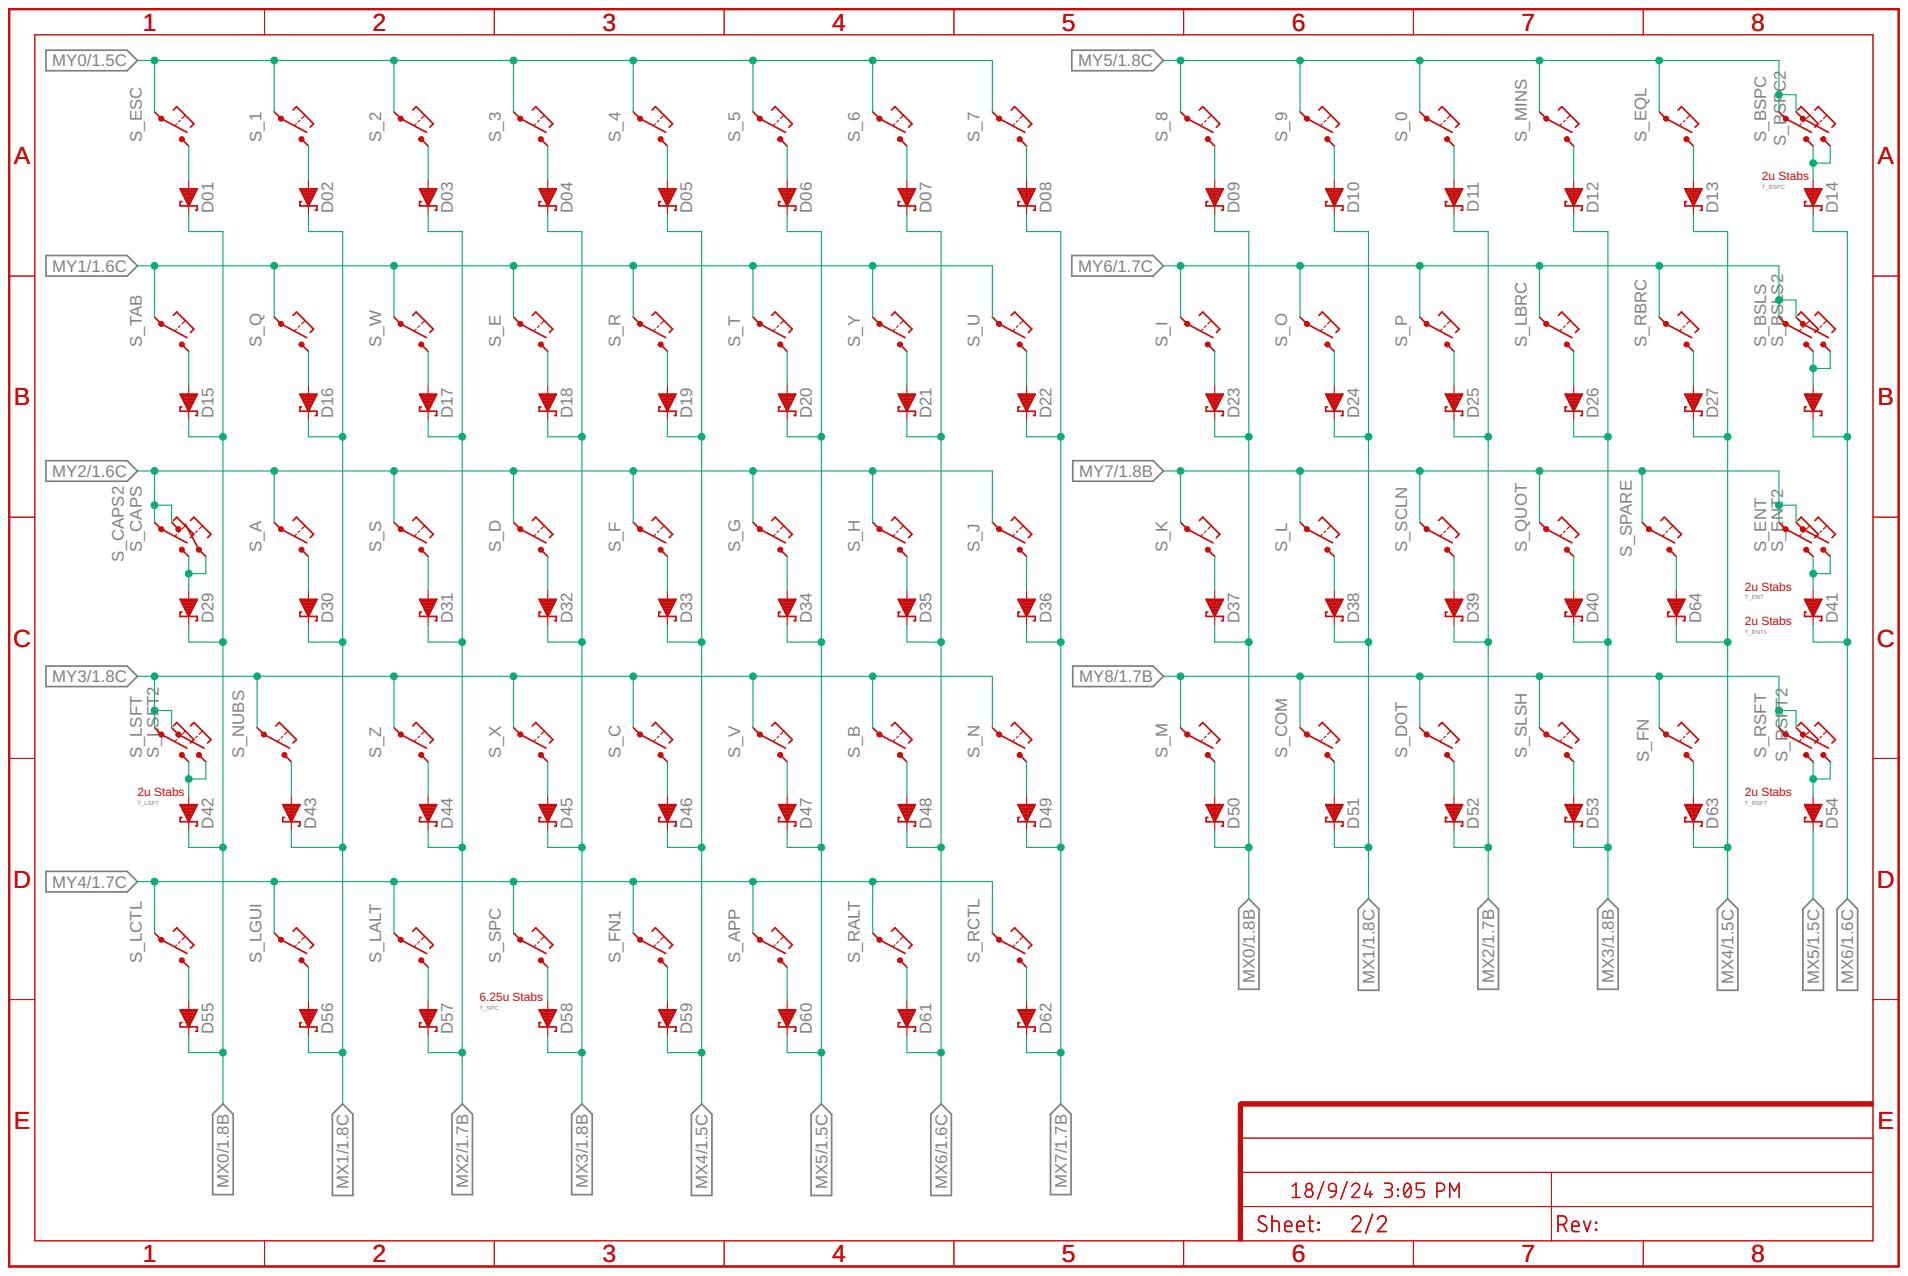
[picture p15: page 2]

S_ESC S_1 S_2 S_3 S_4 S_5 S_6 S_7 S_8 S_9 S_0 S_MINS S_EQL S_BSPC D01 D02 D03 D04 D05 D06 D07 D08 D09 D10 D11 D12 D13 D14 S_TAB S_Q S_W S_E S_R S_T S_Y S_U S_I S_O S_P S_LBRC S_RBRC S_BSLS D15 D16 D17 D18 D19 D20 D21 D22 D23 D24 D25 D26 D27 S_CAPS S_A S_S S_D S_F S_G S_H S_J S_K S_L S_SCLN S_QUOT S_ENT D29 D30 D31 D32 D33 D34 D35 D36 D37 D38 D39 D40 D41 S_LSFT S_Z S_X S_C S_V S_B S_N S_M S_COM S_DOT S_SLSH S_RSFT D42 D44 D45 D46 D47 D48 D49 D50 D51 D52 D53 D54 S_LCTL S_LGUI S_LALT S_SPC S_FN1 S_APP S_RALT S_RCTL D55 D56 D57 D58 D59 D60 D61 D62 T_BSPC T_ENT T_LSFT T_RSFT T_SPC D43 S_NUBS S_LSFT2 S_ENT2 S_BSLS2 T_ENT1 D63 S_RSFT2 S_FN S_BSPC2 S_SPARE D64 S_CAPS2 MY0/1.5C MY1/1.6C MY2/1.6C MY3/1.8C MY4/1.7C MY5/1.8C MY6/1.7C MY7/1.8B MY8/1.7B MX5/1.5C MX5/1.5C MX6/1.6C MX6/1.6C MX7/1.7B MX0/1.8B MX0/1.8B MX1/1.8C MX1/1.8C MX2/1.7B MX2/1.7B MX3/1.8B MX3/1.8B MX4/1.5C MX4/1.5C ABCDE 1 2 3 4 5 6 7 8 ABCDE 1 2 3 4 5 6 7 8 ABCDE 1 2 3 4 5 6 7 8 ABCDE 1 2 3 4 5 6 7 82u Stabs 2u Stabs 2u Stabs 2u Stabs 6.25u Stabs 2u Stabs

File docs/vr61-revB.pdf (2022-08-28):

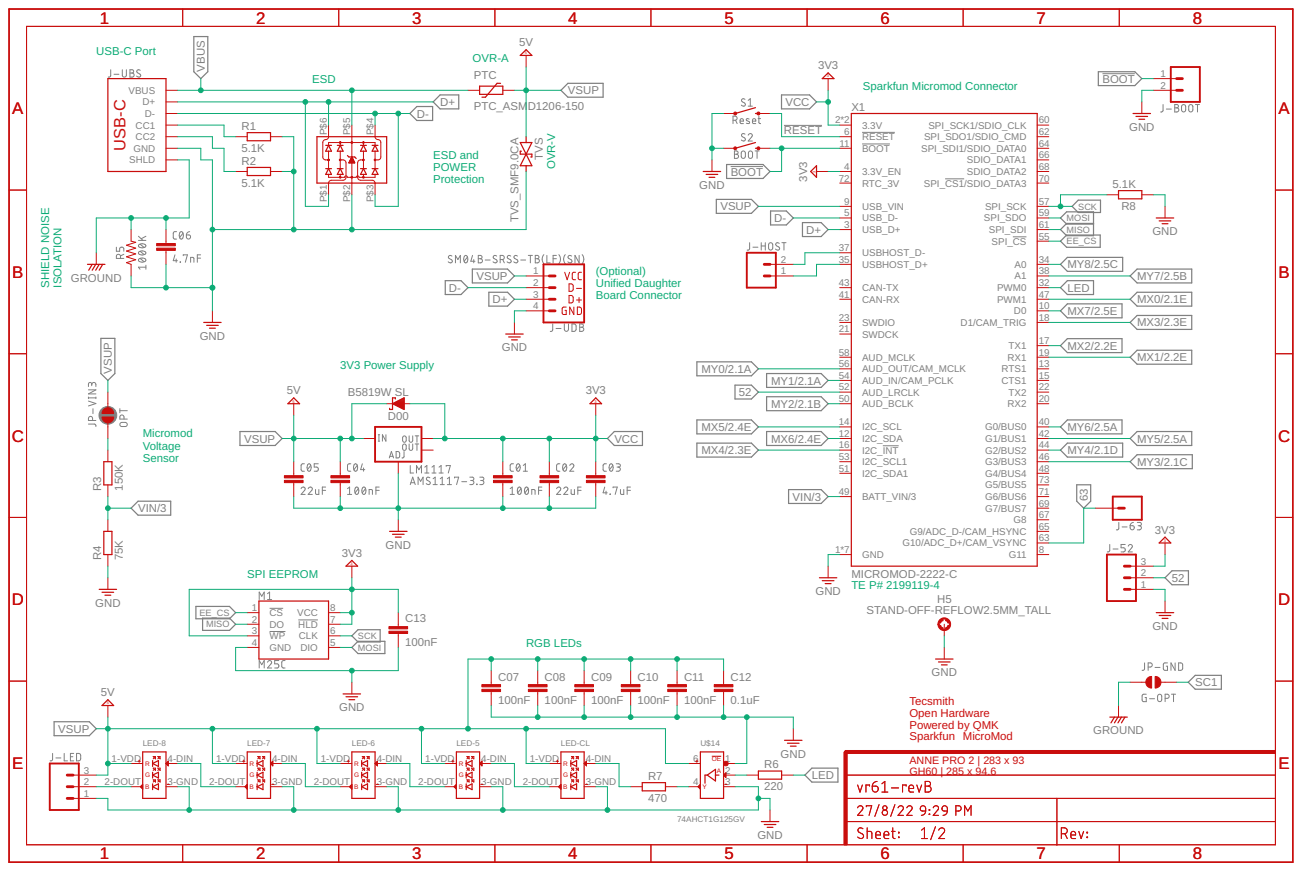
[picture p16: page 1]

(Optional)
Unified Daughter Board Connector

Tecsmith
Open Hardware Sparkfun Powered by QMK

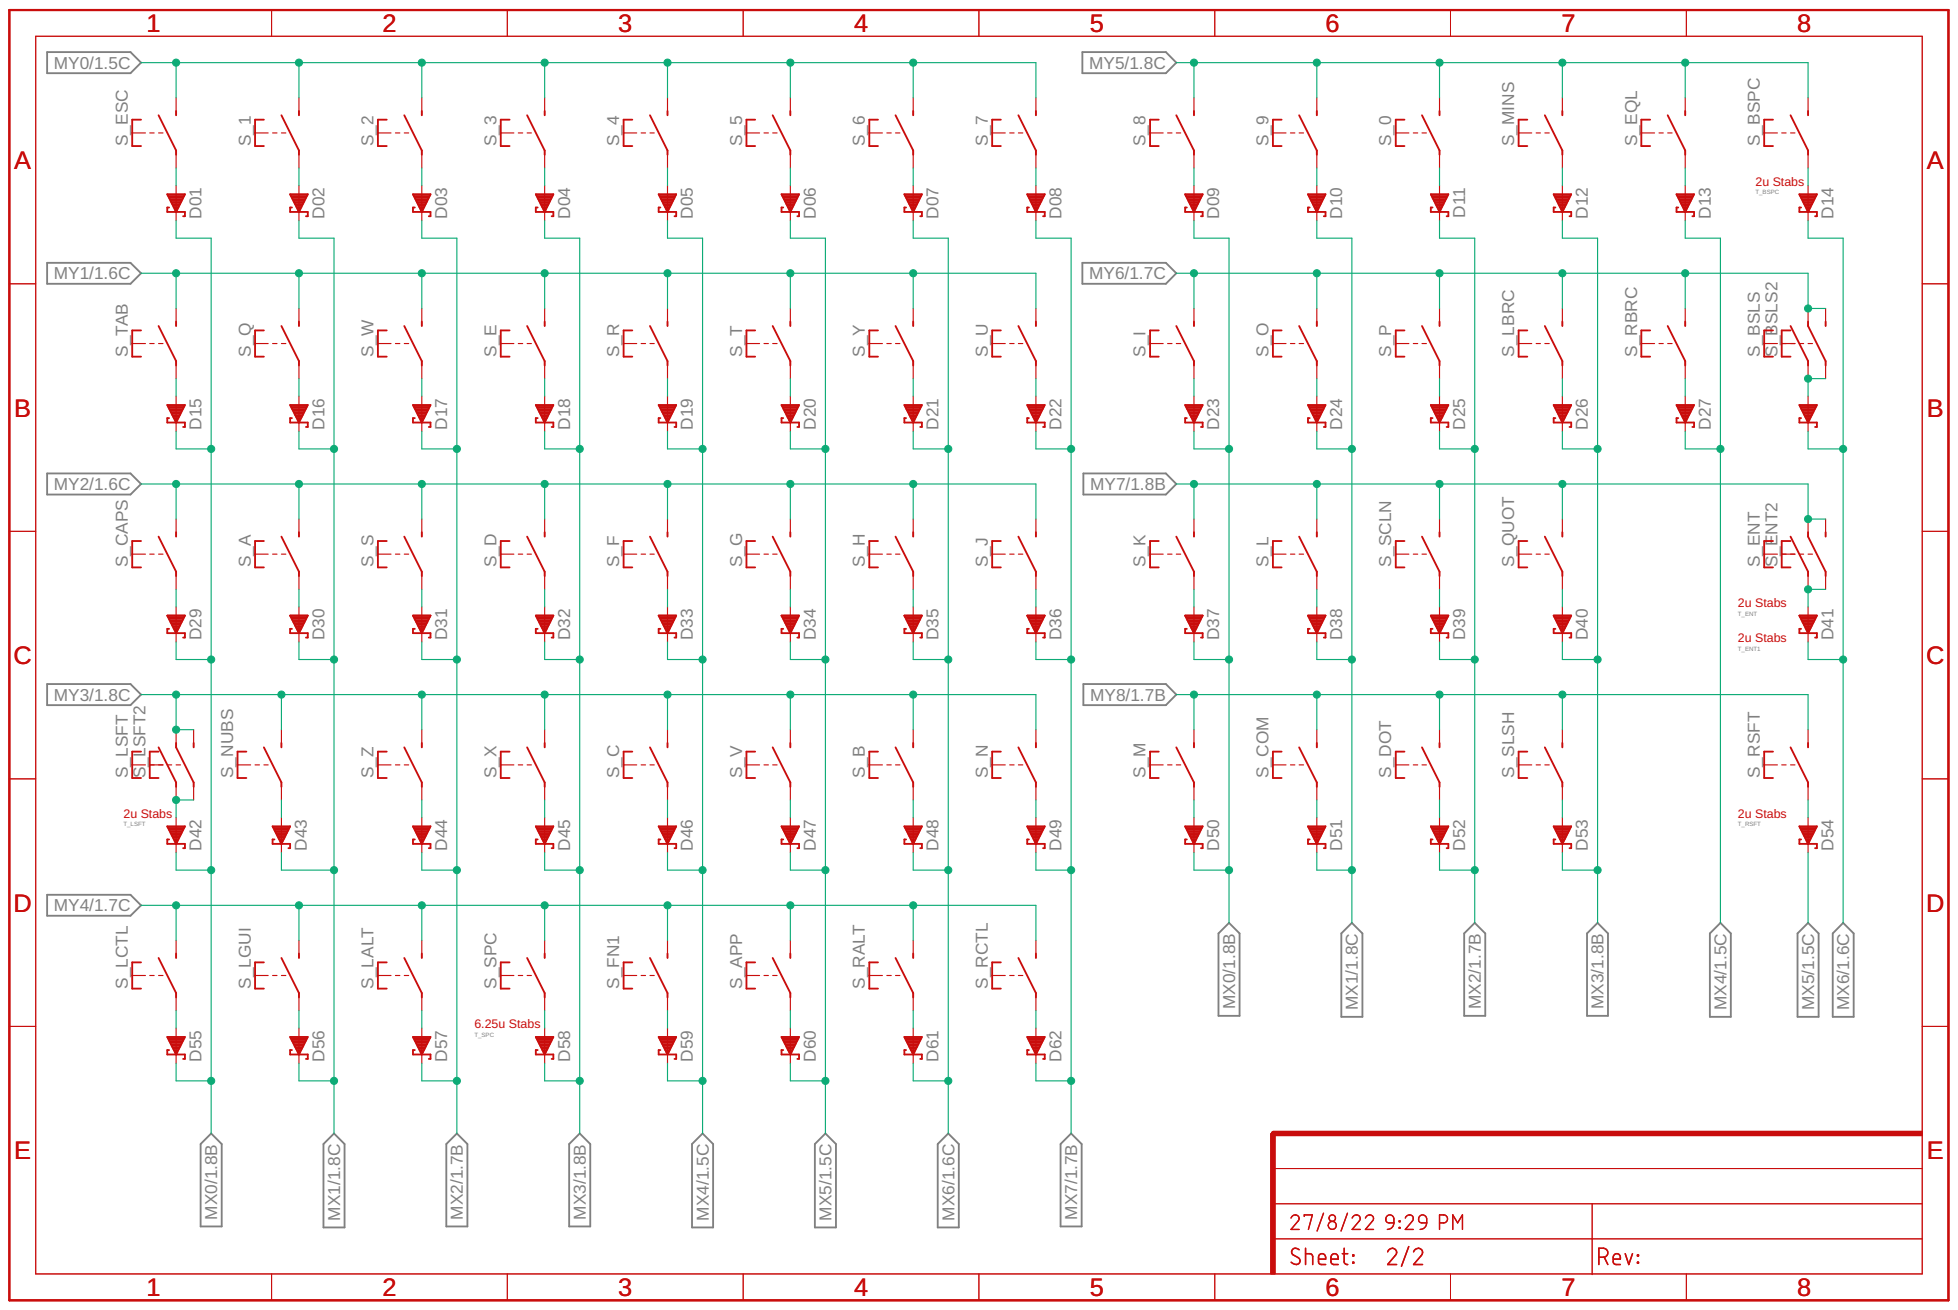
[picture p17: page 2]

S_ESC S_1 S_2 S_3 S_4 S_5 S_6 S_7 S_8 S_9 S_0 S_MINS S_EQL S_BSPC D01 D02 D03 D04 D05 D06 D07 D08 D09 D10 D11 D12 D13 D14 S_TAB S_Q S_W S_E S_R S_T S_Y S_U S_I S_O S_P S_LBRC S_RBRC S_BSLS D15 D16 D17 D18 D19 D20 D21 D22 D23 D24 D25 D26 D27 S_CAPS S_A S_S S_D S_F S_G S_H S_J S_K S_L S_SCLN S_QUOT S_ENT D29 D30 D31 D32 D33 D34 D35 D36 D37 D38 D39 D40 D41 S_LSFT S_Z S_X S_C S_V S_B S_N S_M S_COM S_DOT S_SLSH S_RSFT D42 D44 D45 D46 D47 D48 D49 D50 D51 D52 D53 D54 S_LCTL S_LGUI S_LALT S_SPC S_FN1 S_APP S_RALT S_RCTL D55 D56 D57 D58 D59 D60 D61 D62 T_BSPC T_ENT T_LSFT T_RSFT T_SPC D43 S_NUBS S_LSFT2 S_ENT2 S_BSLS2 T_ENT1 MY0/1.5C MY1/1.6C MY2/1.6C MY3/1.8C MY4/1.7C MY5/1.8C MY6/1.7C MY7/1.8B MY8/1.7B MX5/1.5C MX5/1.5C MX6/1.6C MX6/1.6C MX7/1.7B MX0/1.8B MX0/1.8B MX1/1.8C MX1/1.8C MX2/1.7B MX2/1.7B MX3/1.8B MX3/1.8B MX4/1.5C MX4/1.5C ABCDE 1 2 3 4 5 6 7 8 ABCDE 1 2 3 4 5 6 7 8 ABCDE 1 2 3 4 5 6 7 8 ABCDE 1 2 3 4 5 6 7 8 2u Stabs 2u Stabs 2u Stabs 2u Stabs 6.25u Stabs 2u Stabs

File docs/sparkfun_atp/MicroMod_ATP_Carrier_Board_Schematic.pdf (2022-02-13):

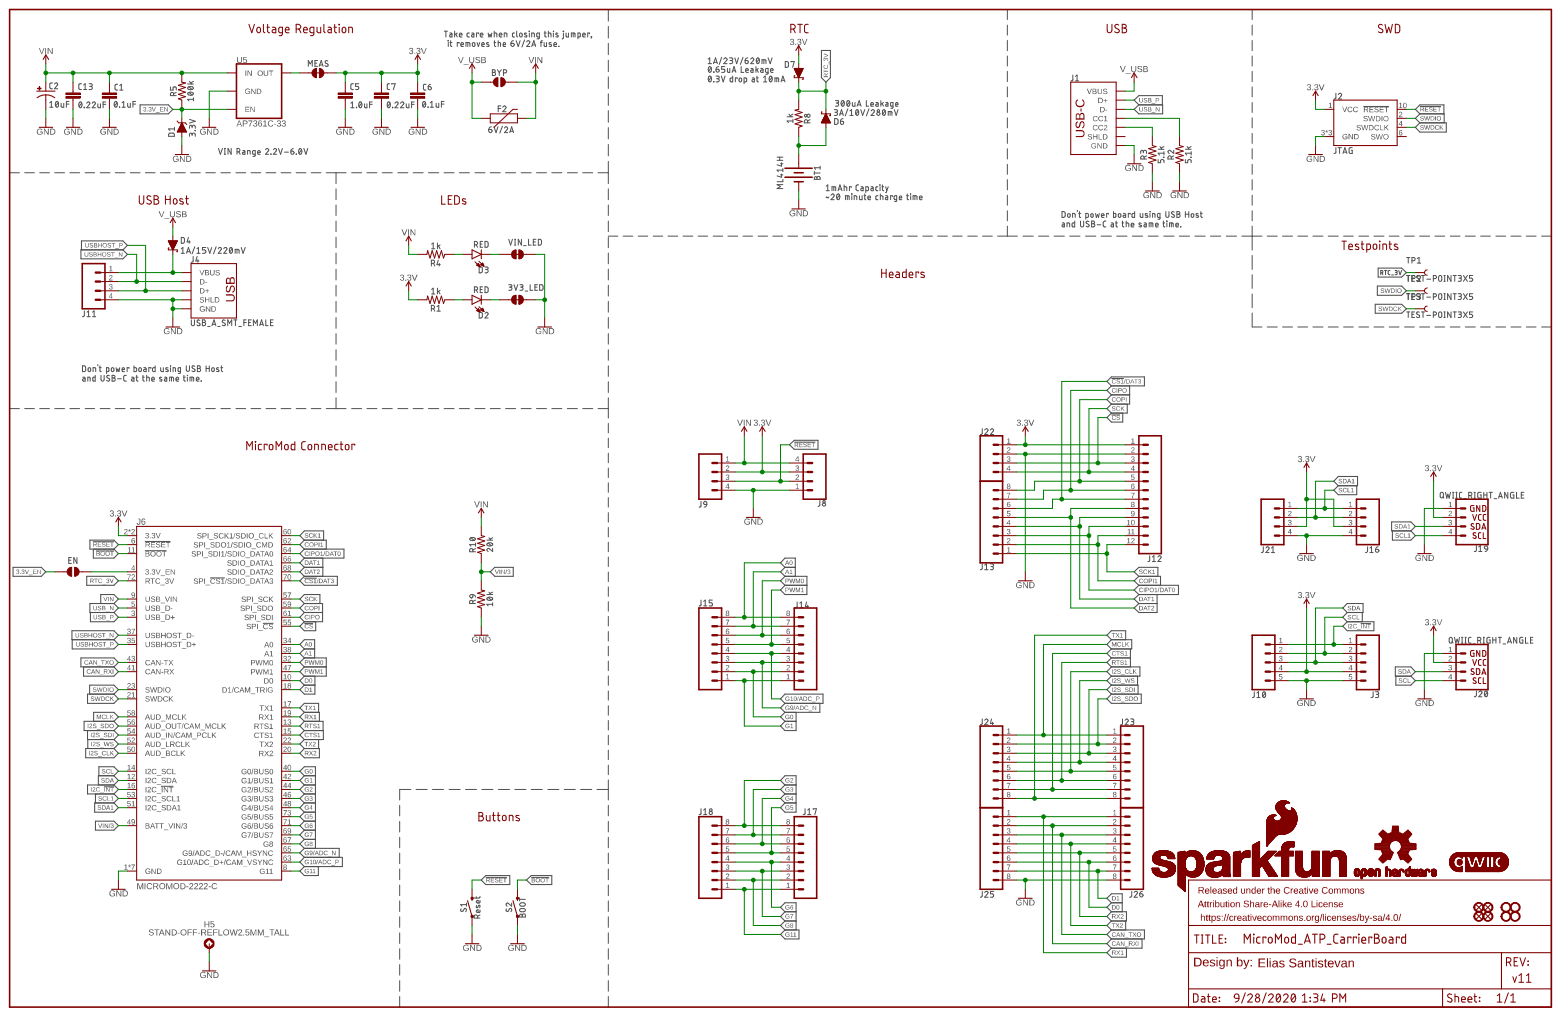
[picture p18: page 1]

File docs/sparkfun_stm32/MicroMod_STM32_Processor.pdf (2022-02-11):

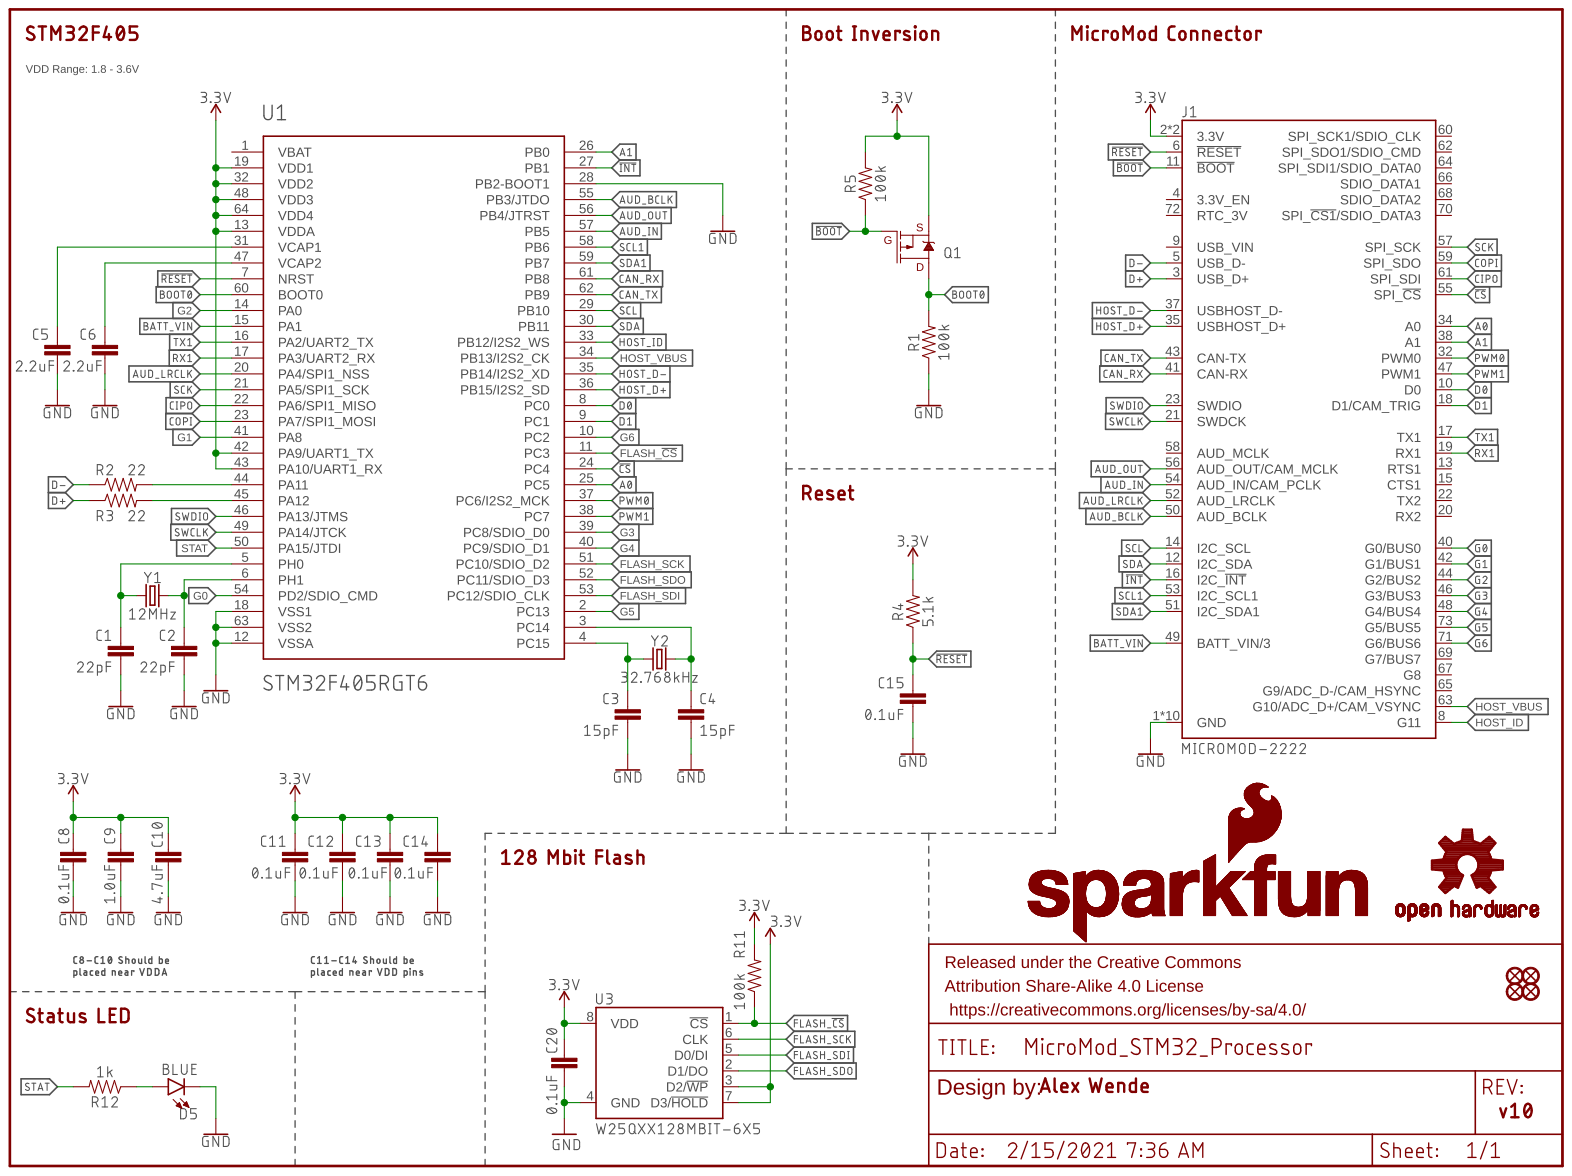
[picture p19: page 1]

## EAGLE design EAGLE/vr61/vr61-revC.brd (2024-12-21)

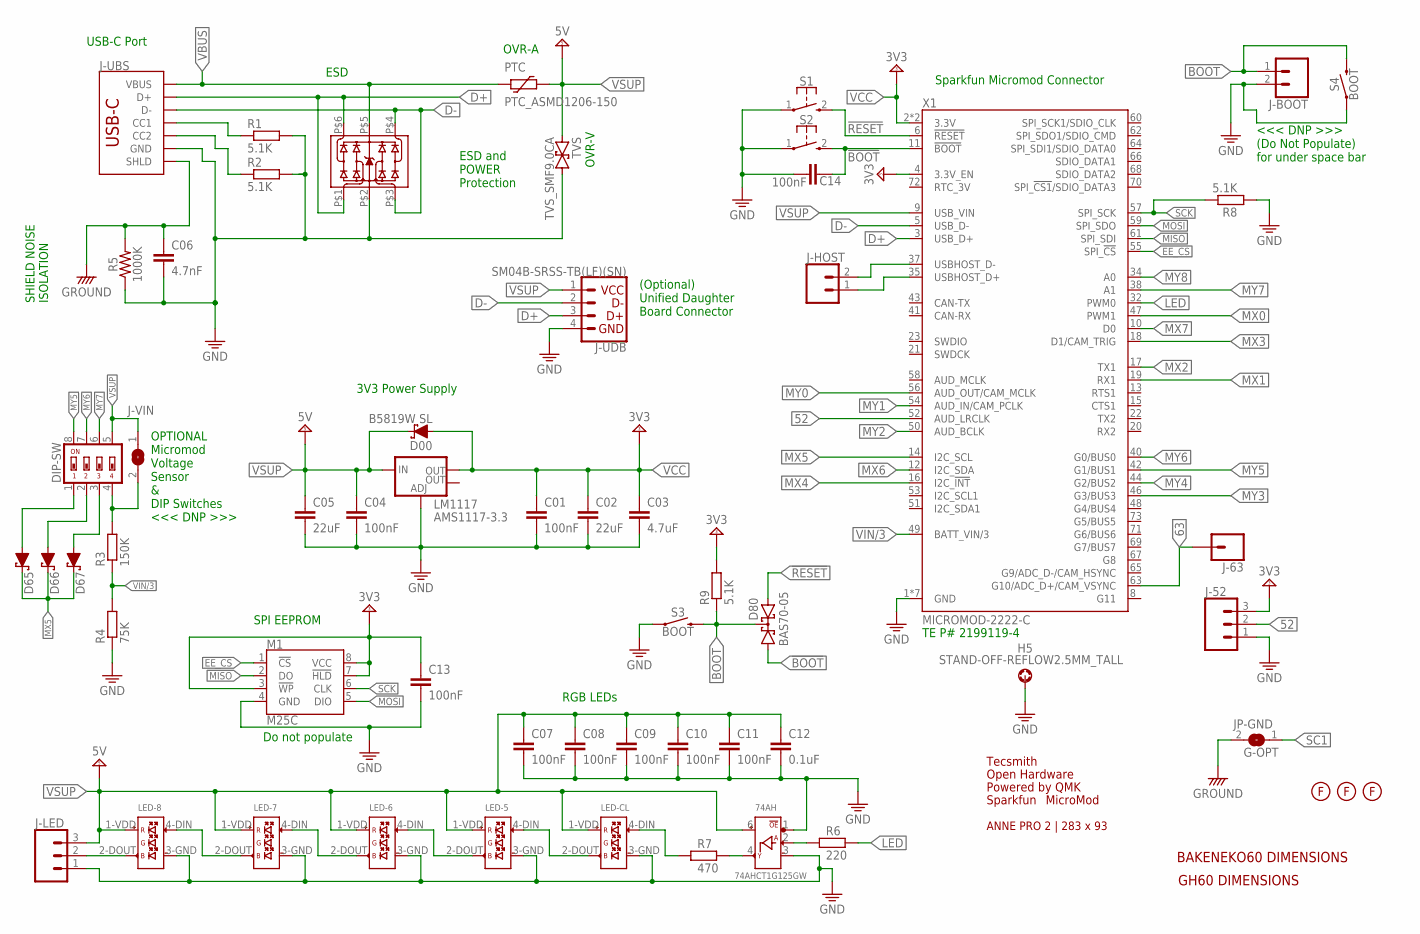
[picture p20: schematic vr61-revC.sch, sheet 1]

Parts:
74AH: 74AHCT1G125GW; SC-88A__TSSOP5__SOT353-1
C01, C04: 100nF; 0603
C02, C05: 22uF; 0603
C03: 4.7uF; 0603
C06: 4.7nF; 0603
C07, C08, C09, C10, C11, C13, C14: 100nF; C0603
C12: 0.1uF; C0603
D00: B5819W SL; SOD-123
D65, D66, D67: 1N5819WS; SOD-123
D80: BAS70-05; SOT23
DIP-SW: DIP004; DIP-1.27-004
ESD: ESD_SRV05-4; SOT-23-6L
FP_AP2: FOOTPRINT-AP2
H5: STAND-OFF-REFLOW2.5MM_TALL; STAND-OFF-REFLOW-M2.5
J-52: CONN_03; 1X03
J-63: CONN_01; 1X01
J-BOOT: CONN_02; 1X02
J-HOST: CONN_02; 1X02
J-LED: CONN_03; 1X03
J-UBS: USB_C_2-LAYER; USB-C-16P
J-UDB: SM04B-SRSS-TB(LF)(SN); 1X04_1MM_RA
J-VIN: JUMPER-1X2; SOLDERJUMPER_ARROW_NOPASTE
JP-GND: G-OPT; SOLDERJUMPER_ARROW_NOPASTE
LED-5, LED-6, LED-7, LED-8: SK6812-E-REVERSE; SK6812-E-MILL
LED-CL: SK6812-E-REVERSE; SK6812-E-MILL
LM1117: AMS1117-3.3; SOT223
LOGO1: OSHW-LOGOL; OSHW-LOGO-L
M1: M25C; 8-SOIC
PTC: PTC_ASMD1206-150; SMD_PTC
R1, R2, R8, R9: 5.1K; R0603
R3: 150K; R0603
R4: 75K; R0603
R5: 1000K; 0603
R6: 220; R0603
R7: 470; R0603
S1, S2: MOMENTARY-SWITCH-SPST-1; SKRKAEE020
S3, S4: BOOT; TACTILE_SWITCH_SMD_5.2MM
TVS: TVS_SMF9.0CA; SOD123FL-BI
U$3: MICROMOD-LOGO
U$5: SPARKFUN_LOGO0.2; SFE_LOGO_NAME_FLAME_.2
U$6: QMK_LOGO
U$8: TECSMITH-LOGOLONG; TECSMITH-NAME
U$20, U$21, U$22: FIDUCIAL
U$24: FOOTPRINT-BAKENEKO60
U$27: FOOTPRINT-DIMS-GH60
X1: MICROMOD-2222-C; M.2-CONNECTOR-E

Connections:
52: J-52.2, X1.52 (AUD_LRCLK)
63: J-63.1, X1.63 (G10/ADC_D+/CAM_VSYNC)
!BOOT: C14.1, D80.1 (A1), S2.2 (3), X1.11 (!BOOT!)
!RESET: D80.2 (A2), S1.2 (3), X1.6 (!RESET!)
BOOT: D80.3 (C), J-BOOT.1, R9.1, S3.3 (2), S3.4 (2), S4.3 (2), S4.4 (2)
CC1: J-UBS.A5 (CC1), R1.1
CC2: J-UBS.B5 (CC2), R2.1
D+: ESD.P$1, ESD.P$6, J-UBS.A6 (D+), J-UBS.B6 (D+), J-UDB.3 (D+), X1.3 (USB_D+)
D-: ESD.P$3, ESD.P$4, J-UBS.A7 (D-), J-UBS.B7 (D-), J-UDB.2 (D-), X1.5 (USB_D-)
EE_CS: M1.1 (!CS), X1.55 (SPI_!CS!)
GND: 74AH.1 (!OE), 74AH.3 (3_GND), C01.2, C02.2, C03.2, C04.2, C05.2, C06.2, C07.2, C08.2, C09.2, C10.2, C11.2, C12.2, C13.2, C14.2, ESD.P$2, H5.1, J-52.1, J-BOOT.2, J-LED.1, J-UBS.GND, J-UBS.GND2 (GND), J-UDB.4 (GND), LED-5.3-GND (3_GND), LED-6.3-GND (3_GND), LED-7.3-GND (3_GND), LED-8.3-GND (3_GND), LED-CL.3-GND (3_GND), LM1117.1 (ADJ), M1.4 (GND), R1.2, R2.2, R4.1, R5.1, R8.1, S1.1, S2.1, S3.1, S3.2 (1), S4.1, S4.2 (1), TVS.P$2 (2), X1.1 (GND), X1.7 (GND), X1.33 (GND), X1.36 (GND), X1.39 (GND), X1.45 (GND), X1.75 (GND)
GROUND: C06.1, J-UBS.SHLD1 (SHLD), J-UBS.SHLD2 (SHLD), J-UBS.SHLD3 (SHLD), J-UBS.SHLD4 (SHLD), J-UBS.SHLD5 (SHLD), J-UBS.SHLD6 (SHLD), J-UBS.SHLD7 (SHLD), J-UBS.SHLD8 (SHLD), JP-GND.2, R5.2
LED: R6.2, X1.32 (PWM0)
LED1ST: 74AH.2 (A_DIN), R6.1
MISO: M1.2 (DO), X1.61 (SPI_SDI)
MOSI: M1.5 (DIO), X1.59 (SPI_SDO)
MX0: X1.47 (PWM1); also elsewhere on the board
MX1: X1.19 (RX1); also elsewhere on the board
MX2: X1.17 (TX1); also elsewhere on the board
MX3: X1.18 (D1/CAM_TRIG); also elsewhere on the board
MX4: X1.16 (I2C_!INT!); also elsewhere on the board
MX5: D65.C, D66.C, D67.C, X1.14 (I2C_SCL); also elsewhere on the board
MX6: X1.12 (I2C_SDA); also elsewhere on the board
MX7: X1.10 (D0); also elsewhere on the board
MY0: X1.56 (AUD_OUT/CAM_MCLK); also elsewhere on the board
MY1: X1.54 (AUD_IN/CAM_PCLK); also elsewhere on the board
MY2: X1.50 (AUD_BCLK); also elsewhere on the board
MY3: X1.46 (G3/BUS3); also elsewhere on the board
MY4: X1.44 (G2/BUS2); also elsewhere on the board
MY5: DIP-SW.8, X1.42 (G1/BUS1); also elsewhere on the board
MY6: DIP-SW.7, X1.40 (G0/BUS0); also elsewhere on the board
MY7: DIP-SW.6, X1.38 (A1); also elsewhere on the board
MY8: X1.34 (A0); also elsewhere on the board
unnamed: LED-5.4-DIN (4_DIN), LED-CL.2-DOUT (2_DOUT)
unnamed: LED-5.2-DOUT (2_DOUT), LED-6.4-DIN (4_DIN)
unnamed: LED-6.2-DOUT (2_DOUT), LED-7.4-DIN (4_DIN)
unnamed: LED-7.2-DOUT (2_DOUT), LED-8.4-DIN (4_DIN)
unnamed: 74AH.4 (Y_DOUT), R7.2
unnamed: LED-CL.4-DIN (4_DIN), R7.1
unnamed: J-LED.2, LED-8.2-DOUT (2_DOUT)
unnamed: D65.A, DIP-SW.1
unnamed: DIP-SW.4, J-VIN.2, R3.2
unnamed: D66.A, DIP-SW.2
unnamed: D67.A, DIP-SW.3
SC1: JP-GND.1
SCK: M1.6 (CLK), R8.2, X1.57 (SPI_SCK)
USBHOST_D+: J-HOST.1, X1.35 (USBHOST_D+)
USBHOST_D-: J-HOST.2, X1.37 (USBHOST_D-)
VBUS: ESD.P$5, J-UBS.VBUS1 (VBUS), J-UBS.VBUS2 (VBUS), PTC.P$1 (1)
VCC: C01.1, C02.1, C03.1, C13.1, D00.A, J-52.3, LM1117.2 (OUT), M1.3 (!WP), M1.7 (!HLD), M1.8 (VCC), R9.2, X1.2 (3.3V), X1.4 (3.3V_EN), X1.74 (3.3V)
VIN/3: R3.1, R4.2, X1.49 (BATT_VIN/3)
VSUP: 74AH.6 (5_VCC), C04.1, C05.1, C07.1, C08.1, C09.1, C10.1, C11.1, C12.1, D00.C, DIP-SW.5, J-LED.3, J-UDB.1 (VCC), J-VIN.1, LED-5.1-VDD (1_VDD), LED-6.1-VDD (1_VDD), LED-7.1-VDD (1_VDD), LED-8.1-VDD (1_VDD), LED-CL.1-VDD (1_VDD), LM1117.3 (IN), PTC.P$2 (2), TVS.P$1 (1), X1.9 (USB_VIN)

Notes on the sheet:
ESD
OVR-A
OVR-V
USB-C Port
ESD and POWER Protection
OPTIONAL Micromod Voltage Sensor & DIP Switches <<< DNP >>>
(Optional) Unified Daughter Board Connector
Sparkfun Micromod Connector
3V3 Power Supply
RGB LEDs
SHIELD NOISE ISOLATION
SPI EEPROM
TE P# 2199119-4
<<< DNP >>> (Do Not Populate) for under space bar
Do not populate

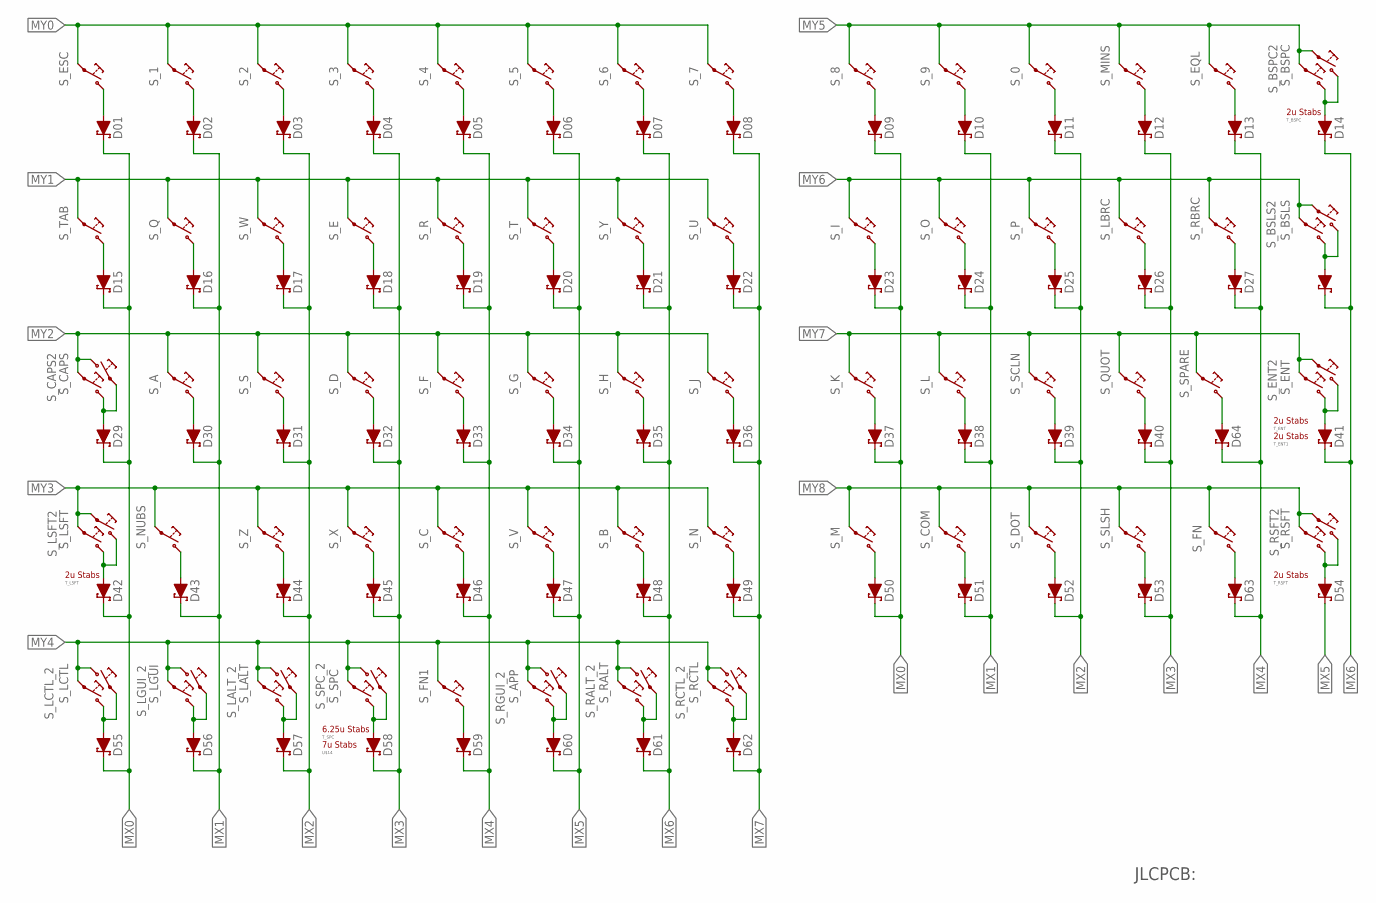
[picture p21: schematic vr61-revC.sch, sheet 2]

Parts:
D01, D02, D03, D04, D05, D06, D07, D08, D09, D10, D11, D12, D13, D14, D15, D16, D17, D18, D19, D20, D21, D22, D23, D24, D25, D26, D27, D28, D29, D30, D31, D32, D33, D34, D35, D36, D37, D38, D39, D40, D41, D42, D43, D44, D45, D46, D47, D48, D49, D50, D51, D52, D53, D54, D55, D56, D57, D58, D59, D60, D61, D62, D63, D64: 1N5819WS; SOD-123
S_0, S_1, S_2, S_3, S_4, S_5, S_6, S_7, S_8, S_9: MX-5-PIN-HOTSWAP-VIA
S_A: MX-5-PIN-HOTSWAP-VIA
S_APP: MX-5-PIN-HOTSWAP-VIA
S_B: MX-5-PIN-HOTSWAP-VIA
S_BSLS: MX-5-PIN-HOTSWAP-VIA
S_BSLS2: MX-5-PIN-HOTSWAP-VIANO-SILK; MX-5-PIN-HOTSWAP-VIA-NS
S_BSPC: MX-5-PIN-HOTSWAP-VIA
S_BSPC2: MX-5-PIN-HOTSWAP-VIANO-SILK; MX-5-PIN-HOTSWAP-VIA-NS
S_C: MX-5-PIN-HOTSWAP-VIA
S_CAPS: MX-5-PIN-HOTSWAP-VIA
S_CAPS2: MX-5-PIN-MILMAX-3305-XNO-SILK; MX-5-PIN-MILMAX-3305-X-NS
S_COM: MX-5-PIN-HOTSWAP-VIA
S_D: MX-5-PIN-HOTSWAP-VIA
S_DOT: MX-5-PIN-HOTSWAP-VIA
S_E: MX-5-PIN-HOTSWAP-VIA
S_ENT: MX-5-PIN-HOTSWAP-VIA
S_ENT2: MX-5-PIN-HOTSWAP-VIANO-SILK; MX-5-PIN-HOTSWAP-VIA-NS
S_EQL: MX-5-PIN-HOTSWAP-VIA
S_ESC: MX-5-PIN-HOTSWAP-VIA
S_F: MX-5-PIN-HOTSWAP-VIA
S_FN: MX-5-PIN-HOTSWAP-VIANO-SILK; MX-5-PIN-HOTSWAP-VIA-NS
S_FN1: MX-5-PIN-HOTSWAP-VIA
S_G: MX-5-PIN-HOTSWAP-VIA
S_H: MX-5-PIN-HOTSWAP-VIA
S_I: MX-5-PIN-HOTSWAP-VIA
S_J: MX-5-PIN-HOTSWAP-VIA
S_K: MX-5-PIN-HOTSWAP-VIA
S_L: MX-5-PIN-HOTSWAP-VIA
S_LALT: MX-5-PIN-HOTSWAP-VIA
S_LALT_2: MX-5-PIN-HOTSWAP-VIANO-SILK; MX-5-PIN-HOTSWAP-VIA-NS
S_LBRC: MX-5-PIN-HOTSWAP-VIA
S_LCTL: MX-5-PIN-HOTSWAP-VIA
S_LCTL_2: MX-5-PIN-HOTSWAP-VIANO-SILK; MX-5-PIN-HOTSWAP-VIA-NS
S_LGUI: MX-5-PIN-HOTSWAP-VIA
S_LGUI_2: MX-5-PIN-HOTSWAP-VIANO-SILK; MX-5-PIN-HOTSWAP-VIA-NS
S_LSFT: MX-5-PIN-HOTSWAP-VIA
S_LSFT2: MX-5-PIN-HOTSWAP-VIANO-SILK; MX-5-PIN-HOTSWAP-VIA-NS
S_M: MX-5-PIN-HOTSWAP-VIA
S_MINS: MX-5-PIN-HOTSWAP-VIA
S_N: MX-5-PIN-HOTSWAP-VIA
S_NUBS: MX-5-PIN-HOTSWAP-VIANO-SILK; MX-5-PIN-HOTSWAP-VIA-NS
S_O: MX-5-PIN-HOTSWAP-VIA
S_P: MX-5-PIN-HOTSWAP-VIA
S_Q: MX-5-PIN-HOTSWAP-VIA
S_QUOT: MX-5-PIN-HOTSWAP-VIA
S_R: MX-5-PIN-HOTSWAP-VIA
S_RALT: MX-5-PIN-HOTSWAP-VIA
S_RALT_2: MX-5-PIN-HOTSWAP-VIANO-SILK; MX-5-PIN-HOTSWAP-VIA-NS
S_RBRC: MX-5-PIN-HOTSWAP-VIA
S_RCTL: MX-5-PIN-HOTSWAP-VIA
S_RCTL_2: MX-5-PIN-HOTSWAP-VIANO-SILK; MX-5-PIN-HOTSWAP-VIA-NS
S_RGUI_2: MX-5-PIN-HOTSWAP-VIANO-SILK; MX-5-PIN-HOTSWAP-VIA-NS
S_RSFT: MX-5-PIN-HOTSWAP-VIA
S_RSFT2: MX-5-PIN-HOTSWAP-VIANO-SILK; MX-5-PIN-HOTSWAP-VIA-NS
S_S: MX-5-PIN-HOTSWAP-VIA
S_SCLN: MX-5-PIN-HOTSWAP-VIA
S_SLSH: MX-5-PIN-HOTSWAP-VIA
S_SPARE: MX-5-PIN-HOTSWAP-VIANO-SILK; MX-5-PIN-HOTSWAP-VIA-NS
S_SPC: MX-5-PIN-HOTSWAP-VIA
S_SPC_2: MX-5-PIN-HOTSWAP-VIANO-SILK; MX-5-PIN-HOTSWAP-VIA-NS
S_T: MX-5-PIN-HOTSWAP-VIA
S_TAB: MX-5-PIN-HOTSWAP-VIA
S_U: MX-5-PIN-HOTSWAP-VIA
S_V: MX-5-PIN-HOTSWAP-VIA
S_W: MX-5-PIN-HOTSWAP-VIA
S_X: MX-5-PIN-HOTSWAP-VIA
S_Y: MX-5-PIN-HOTSWAP-VIA
S_Z: MX-5-PIN-HOTSWAP-VIA
T_BSPC: MX-STABS-200U
T_ENT, T_ENT1: MX-STABS-200U
T_LSFT: MX-STABS-200U
T_RSFT: MX-STABS-200U
T_SPC: MX-STABS-625U
U$14: MX-STABS-700U
U$26: ?; JLC_ORDER_NUMBER_QR_5X5

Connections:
MX0: D01.C, D09.C, D15.C, D23.C, D29.C, D37.C, D42.C, D50.C, D55.C; also elsewhere on the board
MX1: D02.C, D10.C, D16.C, D24.C, D30.C, D38.C, D43.C, D51.C, D56.C; also elsewhere on the board
MX2: D03.C, D11.C, D17.C, D25.C, D31.C, D39.C, D44.C, D52.C, D57.C; also elsewhere on the board
MX3: D04.C, D12.C, D18.C, D26.C, D32.C, D40.C, D45.C, D53.C, D58.C; also elsewhere on the board
MX4: D05.C, D13.C, D19.C, D27.C, D33.C, D46.C, D59.C, D63.C, D64.C; also elsewhere on the board
MX5: D06.C, D20.C, D34.C, D47.C, D54.C, D60.C; also elsewhere on the board
MX6: D07.C, D14.C, D21.C, D28.C, D35.C, D41.C, D48.C, D61.C; also elsewhere on the board
MX7: D08.C, D22.C, D36.C, D49.C, D62.C; also elsewhere on the board
MY0: S_1.2@1 (1), S_1.2@2 (1), S_2.2@1 (1), S_2.2@2 (1), S_3.2@1 (1), S_3.2@2 (1), S_4.2@1 (1), S_4.2@2 (1), S_5.2@1 (1), S_5.2@2 (1), S_6.2@1 (1), S_6.2@2 (1), S_7.2@1 (1), S_7.2@2 (1), S_ESC.2@1 (1), S_ESC.2@2 (1); also elsewhere on the board
MY1: S_E.2@1 (1), S_E.2@2 (1), S_Q.2@1 (1), S_Q.2@2 (1), S_R.2@1 (1), S_R.2@2 (1), S_T.2@1 (1), S_T.2@2 (1), S_TAB.2@1 (1), S_TAB.2@2 (1), S_U.2@1 (1), S_U.2@2 (1), S_W.2@1 (1), S_W.2@2 (1), S_Y.2@1 (1), S_Y.2@2 (1); also elsewhere on the board
MY2: S_A.2@1 (1), S_A.2@2 (1), S_CAPS.2@1 (1), S_CAPS.2@2 (1), S_CAPS2.1 (2), S_D.2@1 (1), S_D.2@2 (1), S_F.2@1 (1), S_F.2@2 (1), S_G.2@1 (1), S_G.2@2 (1), S_H.2@1 (1), S_H.2@2 (1), S_J.2@1 (1), S_J.2@2 (1), S_S.2@1 (1), S_S.2@2 (1); also elsewhere on the board
MY3: S_B.2@1 (1), S_B.2@2 (1), S_C.2@1 (1), S_C.2@2 (1), S_LSFT.2@1 (1), S_LSFT.2@2 (1), S_LSFT2.2@1 (1), S_LSFT2.2@2 (1), S_N.2@1 (1), S_N.2@2 (1), S_NUBS.2@1 (1), S_NUBS.2@2 (1), S_V.2@1 (1), S_V.2@2 (1), S_X.2@1 (1), S_X.2@2 (1), S_Z.2@1 (1), S_Z.2@2 (1); also elsewhere on the board
MY4: S_APP.2@1 (1), S_APP.2@2 (1), S_FN1.2@1 (1), S_FN1.2@2 (1), S_LALT.2@1 (1), S_LALT.2@2 (1), S_LALT_2.1@1 (2), S_LALT_2.1@2 (2), S_LCTL.2@1 (1), S_LCTL.2@2 (1), S_LCTL_2.1@1 (2), S_LCTL_2.1@2 (2), S_LGUI.2@1 (1), S_LGUI.2@2 (1), S_LGUI_2.1@1 (2), S_LGUI_2.1@2 (2), S_RALT.2@1 (1), S_RALT.2@2 (1), S_RALT_2.1@1 (2), S_RALT_2.1@2 (2), S_RCTL.2@1 (1), S_RCTL.2@2 (1), S_RCTL_2.1@1 (2), S_RCTL_2.1@2 (2), S_RGUI_2.1@1 (2), S_RGUI_2.1@2 (2), S_SPC.2@1 (1), S_SPC.2@2 (1), S_SPC_2.1@1 (2), S_SPC_2.1@2 (2); also elsewhere on the board
MY5: S_0.2@1 (1), S_0.2@2 (1), S_8.2@1 (1), S_8.2@2 (1), S_9.2@1 (1), S_9.2@2 (1), S_BSPC.2@1 (1), S_BSPC.2@2 (1), S_BSPC2.2@1 (1), S_BSPC2.2@2 (1), S_EQL.2@1 (1), S_EQL.2@2 (1), S_MINS.2@1 (1), S_MINS.2@2 (1); also elsewhere on the board
MY6: S_BSLS.2@1 (1), S_BSLS.2@2 (1), S_BSLS2.2@1 (1), S_BSLS2.2@2 (1), S_I.2@1 (1), S_I.2@2 (1), S_LBRC.2@1 (1), S_LBRC.2@2 (1), S_O.2@1 (1), S_O.2@2 (1), S_P.2@1 (1), S_P.2@2 (1), S_RBRC.2@1 (1), S_RBRC.2@2 (1); also elsewhere on the board
MY7: S_ENT.2@1 (1), S_ENT.2@2 (1), S_ENT2.2@1 (1), S_ENT2.2@2 (1), S_K.2@1 (1), S_K.2@2 (1), S_L.2@1 (1), S_L.2@2 (1), S_QUOT.2@1 (1), S_QUOT.2@2 (1), S_SCLN.2@1 (1), S_SCLN.2@2 (1), S_SPARE.2@1 (1), S_SPARE.2@2 (1); also elsewhere on the board
MY8: S_COM.2@1 (1), S_COM.2@2 (1), S_DOT.2@1 (1), S_DOT.2@2 (1), S_FN.2@1 (1), S_FN.2@2 (1), S_M.2@1 (1), S_M.2@2 (1), S_RSFT.2@1 (1), S_RSFT.2@2 (1), S_RSFT2.2@1 (1), S_RSFT2.2@2 (1), S_SLSH.2@1 (1), S_SLSH.2@2 (1); also elsewhere on the board
unnamed: D01.A, S_ESC.1@1 (2), S_ESC.1@2 (2)
unnamed: D02.A, S_1.1@1 (2), S_1.1@2 (2)
unnamed: D03.A, S_2.1@1 (2), S_2.1@2 (2)
unnamed: D04.A, S_3.1@1 (2), S_3.1@2 (2)
unnamed: D05.A, S_4.1@1 (2), S_4.1@2 (2)
unnamed: D06.A, S_5.1@1 (2), S_5.1@2 (2)
unnamed: D07.A, S_6.1@1 (2), S_6.1@2 (2)
unnamed: D08.A, S_7.1@1 (2), S_7.1@2 (2)
unnamed: D09.A, S_8.1@1 (2), S_8.1@2 (2)
unnamed: D10.A, S_9.1@1 (2), S_9.1@2 (2)
unnamed: D11.A, S_0.1@1 (2), S_0.1@2 (2)
unnamed: D12.A, S_MINS.1@1 (2), S_MINS.1@2 (2)
unnamed: D13.A, S_EQL.1@1 (2), S_EQL.1@2 (2)
unnamed: D14.A, S_BSPC.1@1 (2), S_BSPC.1@2 (2), S_BSPC2.1@1 (2), S_BSPC2.1@2 (2)
unnamed: D15.A, S_TAB.1@1 (2), S_TAB.1@2 (2)
unnamed: D16.A, S_Q.1@1 (2), S_Q.1@2 (2)
unnamed: D17.A, S_W.1@1 (2), S_W.1@2 (2)
unnamed: D18.A, S_E.1@1 (2), S_E.1@2 (2)
unnamed: D19.A, S_R.1@1 (2), S_R.1@2 (2)
unnamed: D20.A, S_T.1@1 (2), S_T.1@2 (2)
unnamed: D21.A, S_Y.1@1 (2), S_Y.1@2 (2)
unnamed: D22.A, S_U.1@1 (2), S_U.1@2 (2)
unnamed: D23.A, S_I.1@1 (2), S_I.1@2 (2)
unnamed: D24.A, S_O.1@1 (2), S_O.1@2 (2)
unnamed: D25.A, S_P.1@1 (2), S_P.1@2 (2)
unnamed: D26.A, S_LBRC.1@1 (2), S_LBRC.1@2 (2)
unnamed: D27.A, S_RBRC.1@1 (2), S_RBRC.1@2 (2)
unnamed: D28.A, S_BSLS.1@1 (2), S_BSLS.1@2 (2), S_BSLS2.1@1 (2), S_BSLS2.1@2 (2)
unnamed: D30.A, S_A.1@1 (2), S_A.1@2 (2)
unnamed: D31.A, S_S.1@1 (2), S_S.1@2 (2)
unnamed: D32.A, S_D.1@1 (2), S_D.1@2 (2)
unnamed: D33.A, S_F.1@1 (2), S_F.1@2 (2)
unnamed: D34.A, S_G.1@1 (2), S_G.1@2 (2)
unnamed: D35.A, S_H.1@1 (2), S_H.1@2 (2)
unnamed: D36.A, S_J.1@1 (2), S_J.1@2 (2)
unnamed: D37.A, S_K.1@1 (2), S_K.1@2 (2)
unnamed: D38.A, S_L.1@1 (2), S_L.1@2 (2)
unnamed: D39.A, S_SCLN.1@1 (2), S_SCLN.1@2 (2)
unnamed: D40.A, S_QUOT.1@1 (2), S_QUOT.1@2 (2)
unnamed: D41.A, S_ENT.1@1 (2), S_ENT.1@2 (2), S_ENT2.1@1 (2), S_ENT2.1@2 (2)
unnamed: D42.A, S_LSFT.1@1 (2), S_LSFT.1@2 (2), S_LSFT2.1@1 (2), S_LSFT2.1@2 (2)
unnamed: D44.A, S_Z.1@1 (2), S_Z.1@2 (2)
unnamed: D45.A, S_X.1@1 (2), S_X.1@2 (2)
unnamed: D46.A, S_C.1@1 (2), S_C.1@2 (2)
unnamed: D47.A, S_V.1@1 (2), S_V.1@2 (2)
unnamed: D48.A, S_B.1@1 (2), S_B.1@2 (2)
unnamed: D49.A, S_N.1@1 (2), S_N.1@2 (2)
unnamed: D50.A, S_M.1@1 (2), S_M.1@2 (2)
unnamed: D51.A, S_COM.1@1 (2), S_COM.1@2 (2)
unnamed: D52.A, S_DOT.1@1 (2), S_DOT.1@2 (2)
unnamed: D53.A, S_SLSH.1@1 (2), S_SLSH.1@2 (2)
unnamed: D54.A, S_RSFT.1@1 (2), S_RSFT.1@2 (2), S_RSFT2.1@1 (2), S_RSFT2.1@2 (2)
unnamed: D55.A, S_LCTL.1@1 (2), S_LCTL.1@2 (2), S_LCTL_2.2@1 (1), S_LCTL_2.2@2 (1)
unnamed: D56.A, S_LGUI.1@1 (2), S_LGUI.1@2 (2), S_LGUI_2.2@1 (1), S_LGUI_2.2@2 (1)
unnamed: D57.A, S_LALT.1@1 (2), S_LALT.1@2 (2), S_LALT_2.2@1 (1), S_LALT_2.2@2 (1)
unnamed: D58.A, S_SPC.1@1 (2), S_SPC.1@2 (2), S_SPC_2.2@1 (1), S_SPC_2.2@2 (1)
unnamed: D59.A, S_FN1.1@1 (2), S_FN1.1@2 (2)
unnamed: D60.A, S_APP.1@1 (2), S_APP.1@2 (2), S_RGUI_2.2@1 (1), S_RGUI_2.2@2 (1)
unnamed: D61.A, S_RALT.1@1 (2), S_RALT.1@2 (2), S_RALT_2.2@1 (1), S_RALT_2.2@2 (1)
unnamed: D62.A, S_RCTL.1@1 (2), S_RCTL.1@2 (2), S_RCTL_2.2@1 (1), S_RCTL_2.2@2 (1)
unnamed: D29.A, S_CAPS.1@1 (2), S_CAPS.1@2 (2), S_CAPS2.2 (1)
unnamed: D43.A, S_NUBS.1@1 (2), S_NUBS.1@2 (2)
unnamed: D64.A, S_SPARE.1@1 (2), S_SPARE.1@2 (2)
unnamed: D63.A, S_FN.1@1 (2), S_FN.1@2 (2)

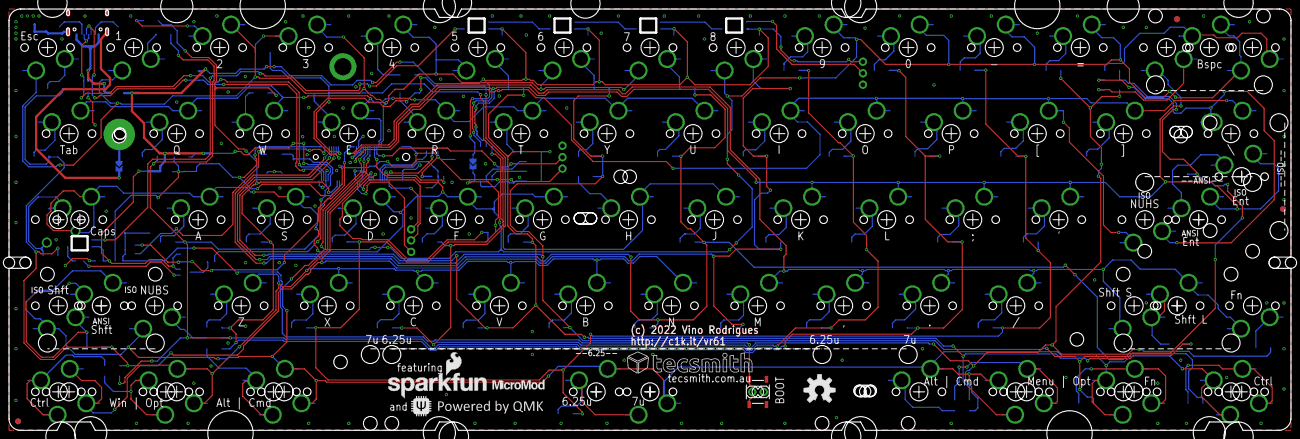
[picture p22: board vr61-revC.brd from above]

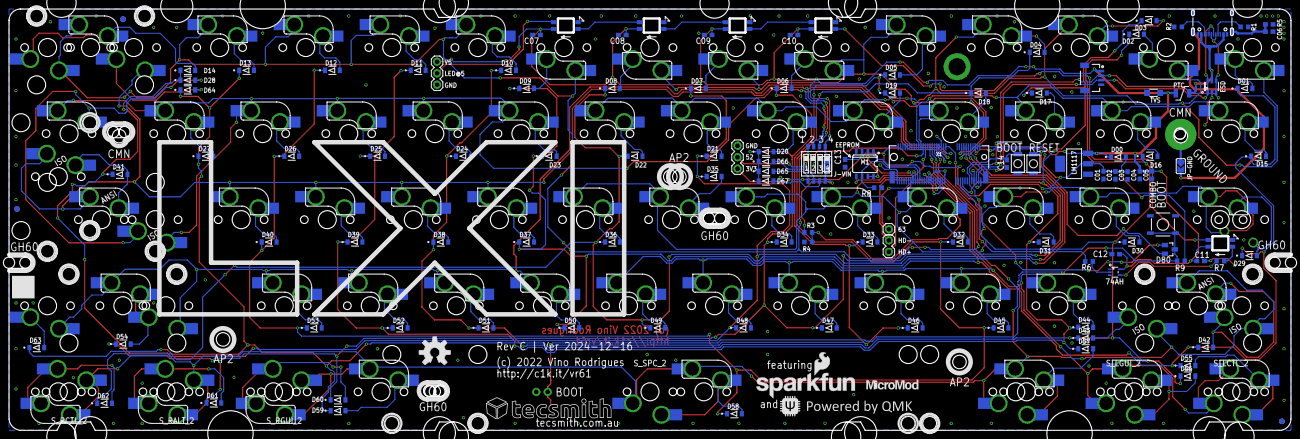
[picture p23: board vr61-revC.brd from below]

Board: 2 copper layers, 283.8 x 93.2 mm, 220 parts (117 on the bottom side), 115 nets.

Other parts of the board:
LOGO2: OSHW-LOGOL; OSHW-LOGO-L
U$7: TECSMITH-LOGOLONG; TECSMITH-NAME
U$10: SPARKFUN_LOGO0.2; SFE_LOGO_NAME_FLAME_.2
U$12: QMK_LOGO
U$13: MICROMOD-LOGO

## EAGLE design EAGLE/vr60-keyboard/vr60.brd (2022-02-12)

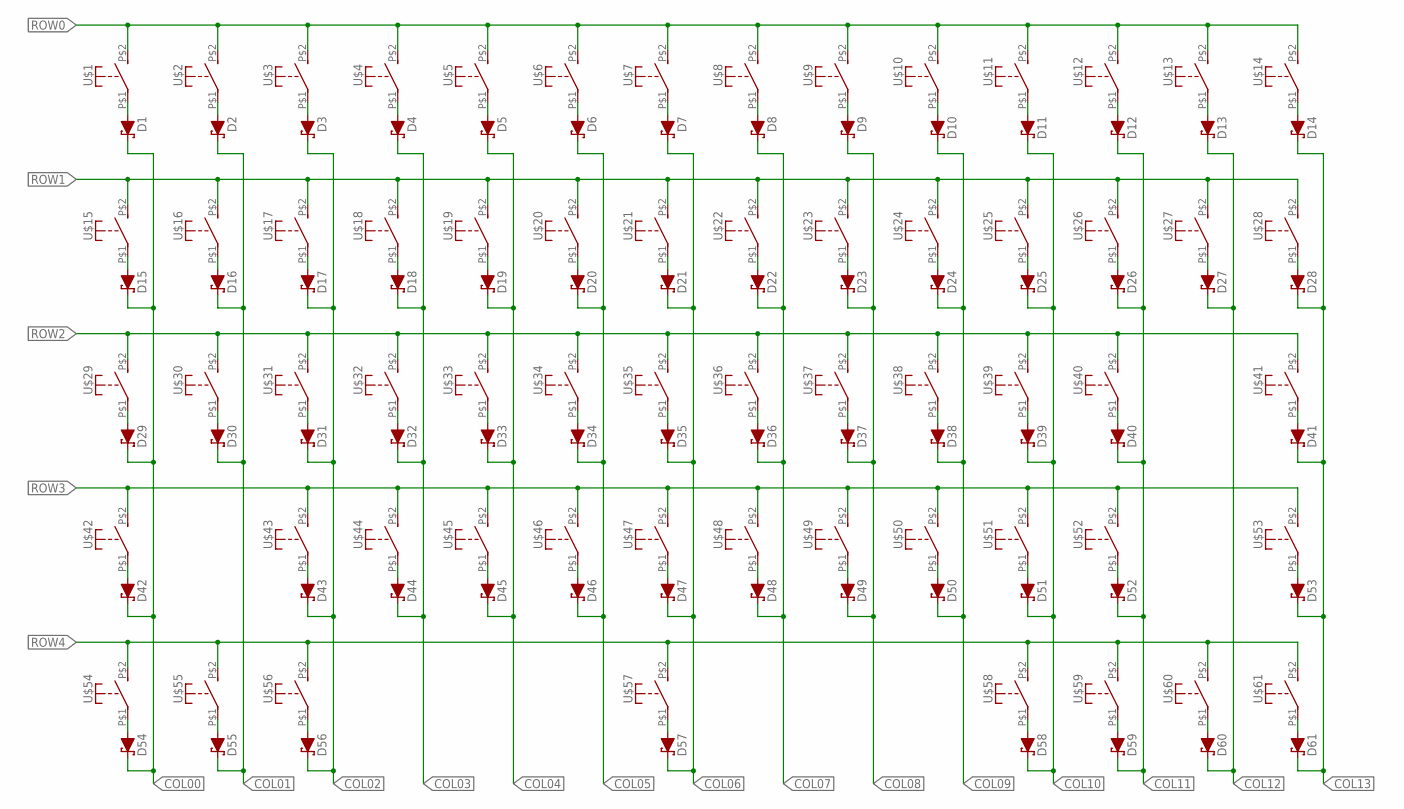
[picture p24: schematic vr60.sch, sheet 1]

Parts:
D1, D2, D3, D4, D5, D6, D7, D8, D9, D10, D11, D12, D13, D14, D15, D16, D17, D18, D19, D20, D21, D22, D23, D24, D25, D26, D27, D28, D29, D30, D31, D32, D33, D34, D35, D36, D37, D38, D39, D40, D41, D42, D43, D44, D45, D46, D47, D48, D49, D50, D51, D52, D53, D54, D55, D56, D57, D58, D59, D60, D61: 1N5819WS; SOD-123
U$1, U$2, U$3, U$4, U$5, U$6, U$7, U$8, U$9, U$10, U$11, U$12, U$13, U$14, U$15, U$16, U$17, U$18, U$19, U$20, U$21, U$22, U$23, U$24, U$25, U$26, U$27, U$28, U$29, U$30, U$31, U$32, U$33, U$34, U$35, U$36, U$37, U$38, U$39, U$40, U$41, U$42, U$43, U$44, U$45, U$46, U$47, U$48, U$49, U$50, U$51, U$52, U$53, U$54, U$55, U$56, U$57, U$58, U$59, U$60, U$61: MX-5-PIN-HOTSWAP

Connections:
COL00: D1.C, D15.C, D29.C, D42.C, D54.C
COL01: D2.C, D16.C, D30.C, D55.C
COL02: D3.C, D17.C, D31.C, D43.C, D56.C
COL03: D4.C, D18.C, D32.C, D44.C
COL04: D5.C, D19.C, D33.C, D45.C
COL05: D6.C, D20.C, D34.C, D46.C
COL06: D7.C, D21.C, D35.C, D47.C, D57.C
COL07: D8.C, D22.C, D36.C, D48.C
COL08: D9.C, D23.C, D37.C, D49.C
COL09: D10.C, D24.C, D38.C, D50.C
COL10: D11.C, D25.C, D39.C, D51.C, D58.C
COL11: D12.C, D26.C, D40.C, D52.C, D59.C
COL12: D13.C, D27.C, D60.C
COL13: D14.C, D28.C, D41.C, D53.C, D61.C
unnamed: D1.A, U$1.P$1
unnamed: D2.A, U$2.P$1
unnamed: D3.A, U$3.P$1
unnamed: D4.A, U$4.P$1
unnamed: D5.A, U$5.P$1
unnamed: D6.A, U$6.P$1
unnamed: D7.A, U$7.P$1
unnamed: D8.A, U$8.P$1
unnamed: D9.A, U$9.P$1
unnamed: D10.A, U$10.P$1
unnamed: D11.A, U$11.P$1
unnamed: D12.A, U$12.P$1
unnamed: D13.A, U$13.P$1
unnamed: D14.A, U$14.P$1
unnamed: D15.A, U$15.P$1
unnamed: D16.A, U$16.P$1
unnamed: D17.A, U$17.P$1
unnamed: D18.A, U$18.P$1
unnamed: D19.A, U$19.P$1
unnamed: D20.A, U$20.P$1
unnamed: D21.A, U$21.P$1
unnamed: D22.A, U$22.P$1
unnamed: D23.A, U$23.P$1
unnamed: D24.A, U$24.P$1
unnamed: D25.A, U$25.P$1
unnamed: D26.A, U$26.P$1
unnamed: D27.A, U$27.P$1
unnamed: D28.A, U$28.P$1
unnamed: D29.A, U$29.P$1
unnamed: D30.A, U$30.P$1
unnamed: D31.A, U$31.P$1
unnamed: D32.A, U$32.P$1
unnamed: D33.A, U$33.P$1
unnamed: D34.A, U$34.P$1
unnamed: D35.A, U$35.P$1
unnamed: D36.A, U$36.P$1
unnamed: D37.A, U$37.P$1
unnamed: D38.A, U$38.P$1
unnamed: D39.A, U$39.P$1
unnamed: D40.A, U$40.P$1
unnamed: D41.A, U$41.P$1
unnamed: D42.A, U$42.P$1
unnamed: D43.A, U$43.P$1
unnamed: D44.A, U$44.P$1
unnamed: D45.A, U$45.P$1
unnamed: D46.A, U$46.P$1
unnamed: D47.A, U$47.P$1
unnamed: D48.A, U$48.P$1
unnamed: D49.A, U$49.P$1
unnamed: D50.A, U$50.P$1
unnamed: D51.A, U$51.P$1
unnamed: D52.A, U$52.P$1
unnamed: D53.A, U$53.P$1
unnamed: D54.A, U$54.P$1
unnamed: D55.A, U$55.P$1
unnamed: D56.A, U$56.P$1
unnamed: D57.A, U$57.P$1
unnamed: D58.A, U$58.P$1
unnamed: D59.A, U$59.P$1
unnamed: D60.A, U$60.P$1
unnamed: D61.A, U$61.P$1
ROW0: U$1.P$2 (S), U$2.P$2 (S), U$3.P$2 (S), U$4.P$2 (S), U$5.P$2 (S), U$6.P$2 (S), U$7.P$2 (S), U$8.P$2 (S), U$9.P$2 (S), U$10.P$2 (S), U$11.P$2 (S), U$12.P$2 (S), U$13.P$2 (S), U$14.P$2 (S)
ROW1: U$15.P$2 (S), U$16.P$2 (S), U$17.P$2 (S), U$18.P$2 (S), U$19.P$2 (S), U$20.P$2 (S), U$21.P$2 (S), U$22.P$2 (S), U$23.P$2 (S), U$24.P$2 (S), U$25.P$2 (S), U$26.P$2 (S), U$27.P$2 (S), U$28.P$2 (S)
ROW2: U$29.P$2 (S), U$30.P$2 (S), U$31.P$2 (S), U$32.P$2 (S), U$33.P$2 (S), U$34.P$2 (S), U$35.P$2 (S), U$36.P$2 (S), U$37.P$2 (S), U$38.P$2 (S), U$39.P$2 (S), U$40.P$2 (S), U$41.P$2 (S)
ROW3: U$42.P$2 (S), U$43.P$2 (S), U$44.P$2 (S), U$45.P$2 (S), U$46.P$2 (S), U$47.P$2 (S), U$48.P$2 (S), U$49.P$2 (S), U$50.P$2 (S), U$51.P$2 (S), U$52.P$2 (S), U$53.P$2 (S)
ROW4: U$54.P$2 (S), U$55.P$2 (S), U$56.P$2 (S), U$57.P$2 (S), U$58.P$2 (S), U$59.P$2 (S), U$60.P$2 (S), U$61.P$2 (S)

Board: 2 copper layers, 122 parts (0 on the bottom side), 80 nets, no tracks yet.

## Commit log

2022-02-04 initial and empty
    [vr60.kicad_pcb, vr60.kicad_sch]
2022-02-05 initial footprint
    [vr60.brd, vr60.sch]
2022-05-21 Create 3.3v protect and measure.png
2022-05-22 sort docs
    [MicroMod-RP2040-ProcessorBoard.brd, MicroMod-RP2040-ProcessorBoard.sch, MicroMod_ATP_CarrierBoard.brd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]
2022-05-31 additional protection & diode placements
    [vr60.brd, vr60.sch]
2022-06-04 pcb tracing done
    [vr60.brd, vr60.sch]
2022-06-05 added heat sink on 1117
    [vr60.brd, vr60.sch]
2022-06-05 wip, logos
    [vr60.brd, vr60.sch]
2022-06-06 logos and text
    [vr60.brd, vr60.sch]
2022-06-06 i think it's ready
    [vr61.brd]
2022-06-06 correct micromod logo
    [vr61.brd, vr61.sch]
2022-06-06 updates after peer review on qmk discord
    [vr61.brd, vr61.sch]
2022-06-06 minor edit to sch pdf
    [vr61.sch]
2022-06-12 added LED caps
    [vr61.brd, vr61.sch]
2022-06-13 turned top row around
    [vr61.brd, vr61.sch]
2022-06-15 production ready
    [vr61.brd, vr61.sch, vr61_bottom_bom.csv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]
2022-06-17 production ready, rev B
    [c3-udb.brd, c3-udb.sch, jlcpcb_c3-udb_top_bom.csv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]
2022-06-17 forgot ratsnest
    [vr61.brd]
2022-06-17 pcbway sponsoring first prototype build
    [jlcpcb_c3-udb_top_bom.csv, jlcpcb_vr61_bottom_bom.csv, pcbway_jlcpcb_vr61_bottom_bom.csv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]
2022-06-17 thank you pcbway
2022-06-18 update udb
    [c3-udb.brd, c3-udb.sch]
2022-06-18 file renames
    [udb-revC.brd, udb-revC.sch, vr61-revA.brd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]
2022-06-18 not mine to host
    [MicroMod-RP2040-ProcessorBoard.brd, MicroMod-RP2040-ProcessorBoard.sch, MicroMod_ATP_CarrierBoard.brd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]
2022-06-19 updates to docs
    [vr61-revA.sch]
2022-07-20 wip 2022-07-20
    [vr61-revB.brd, vr61-revB.sch]
2022-07-21 wip 2022-07-21
    [vr61-revB.brd, vr61-revB.sch]
2022-07-22 wip 2022-07-22
    [60-footprint.brd, vr61-dims.xlsx, vr61-revB.brd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]
2022-08-27 final touches and validation for rev B
    [vr61-dims.xlsx, vr61-revB.brd, vr61-revB.sch]
2022-08-28 updates after production prep
    [vr61-revB.brd, vr61-revB.sch]
2022-08-30 move r8 + final rev B production files
    [pcbway_jlcpcb_vr61_bottom_bom.csv, vr61-revB.brd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]
2022-08-31 bom fix
    [pcbway_jlcpcb_vr61_bottom_bom.csv]
2022-10-21 adjust centre ap2 drill hole
    [vr61-revB.brd, vr61-revB.sch]
2022-10-30 minor edits
    [vr61-revB.brd, vr61-revB.sch]
2024-09-17 Reb B.2 update
    [build_eagle_positions.OLD.xls, eagle_render.xlsx, vr61-dims.xlsx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]
2024-09-18 Boot switch redo
    [vr61-revB.brd, vr61-revB.sch]
2024-09-20 Added Bakeneko footprint
    [vr61-revB.brd, vr61-revB.sch]
2024-12-21 Rev C
    [eagle_render.xlsx, vr61-revC.brd, vr61-revC.sch]

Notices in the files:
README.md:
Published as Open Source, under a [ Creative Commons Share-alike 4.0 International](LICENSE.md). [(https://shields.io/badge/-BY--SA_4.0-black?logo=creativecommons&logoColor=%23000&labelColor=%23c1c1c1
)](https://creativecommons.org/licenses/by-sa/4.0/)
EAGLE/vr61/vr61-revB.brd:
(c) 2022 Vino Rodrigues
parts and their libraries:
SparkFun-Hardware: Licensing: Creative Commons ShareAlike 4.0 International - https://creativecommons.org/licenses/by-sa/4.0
